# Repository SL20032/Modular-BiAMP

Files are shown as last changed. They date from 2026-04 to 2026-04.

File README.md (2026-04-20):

# Modular-BiAMP
Sample Modular Bi-AMP designed to work with Technics HD501 speakers (bc ampilifre in mine died). Project in active development.

## Modules
- Crosover PCB - Simple Active opamp based crosover providing 80db/dec attenuation. Components selected for 20 Hz to 3kHz passband for low freq part and 3kHz to 20kHz passband for high freq part.
- Power Amp PCB - Amplifire (AB-class) board using LM3886 for low frequence part (woofers) and LM4766 for high Frequency parts (tweeters)

## Fotos
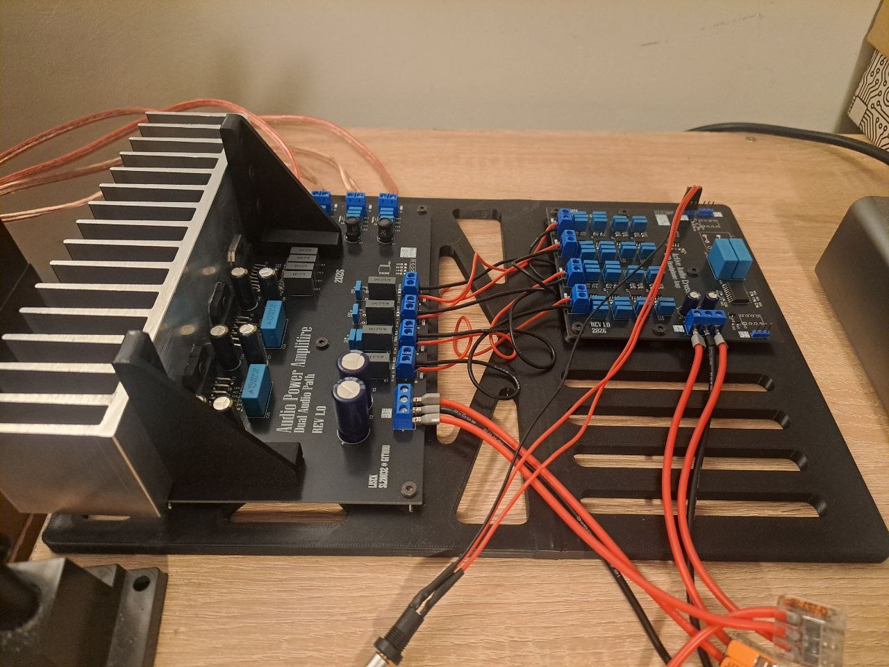
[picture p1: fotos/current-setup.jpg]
Current progress


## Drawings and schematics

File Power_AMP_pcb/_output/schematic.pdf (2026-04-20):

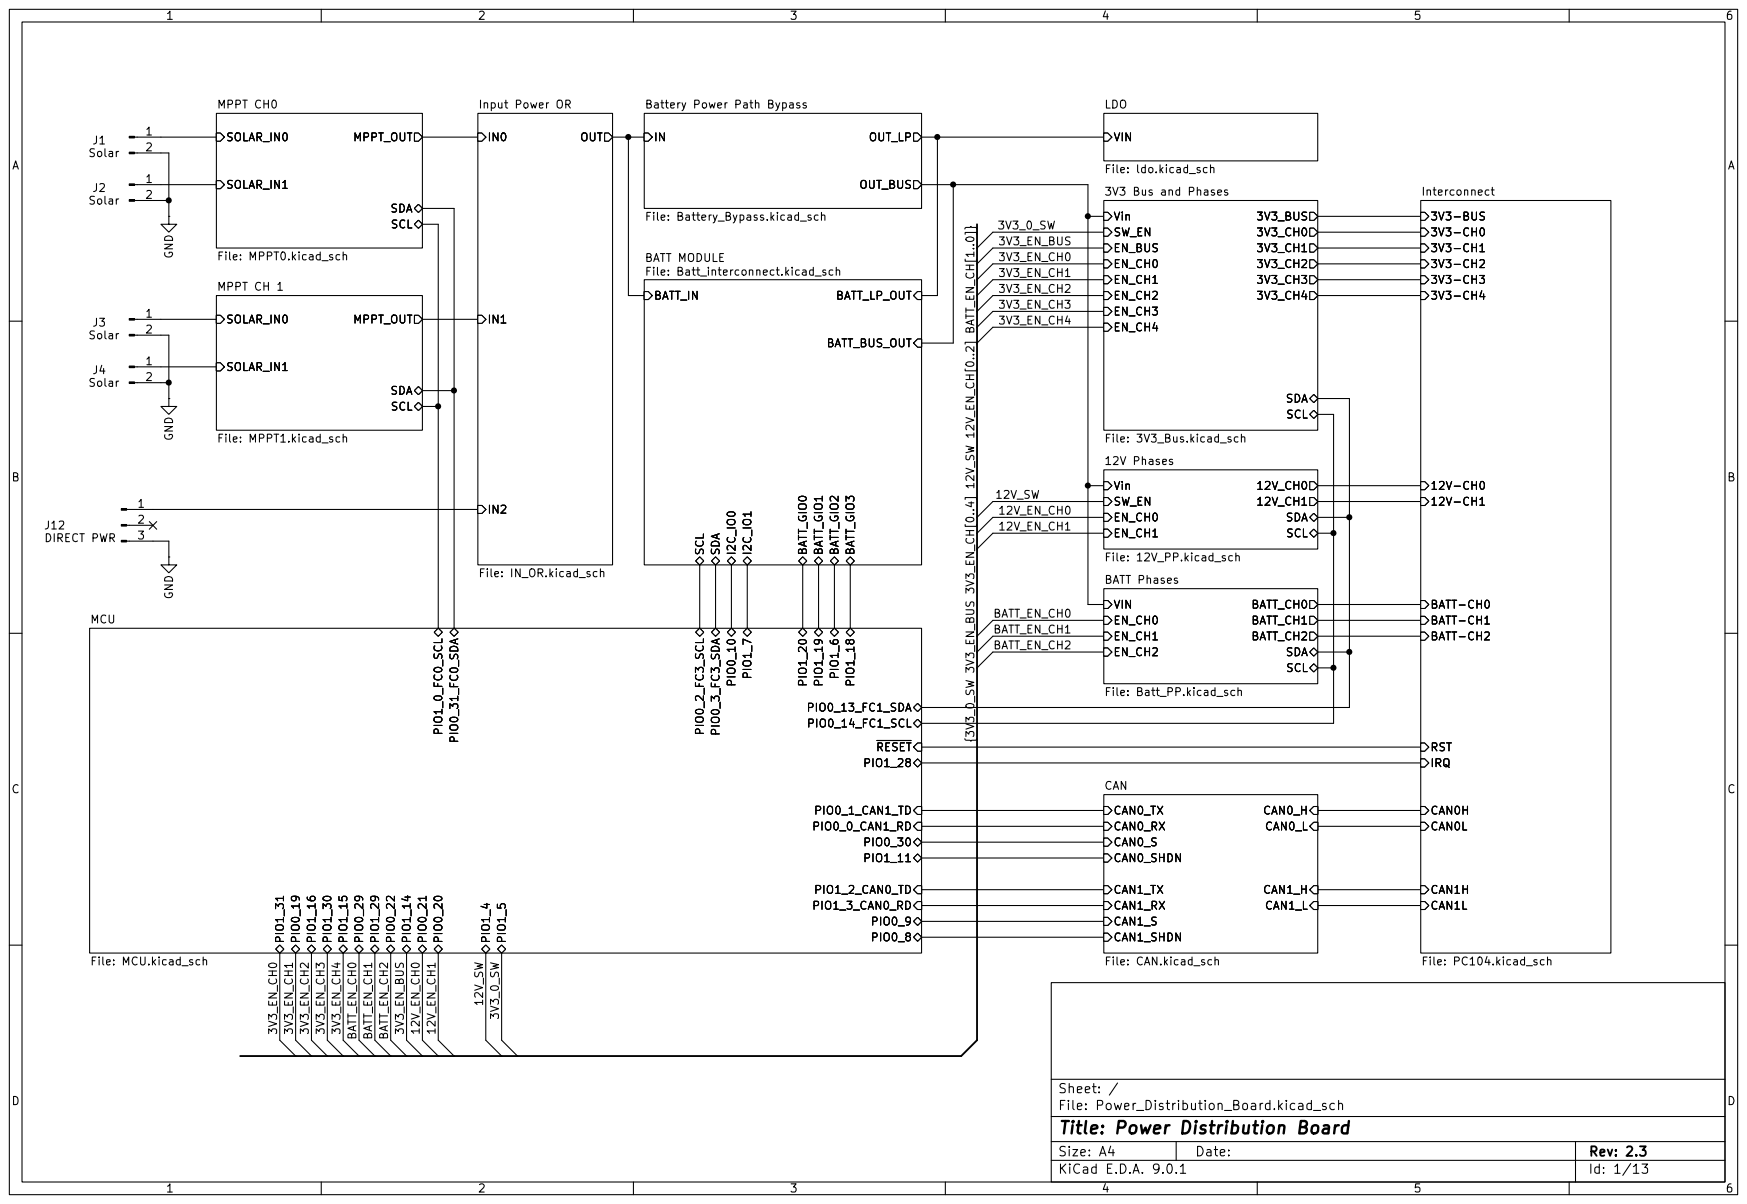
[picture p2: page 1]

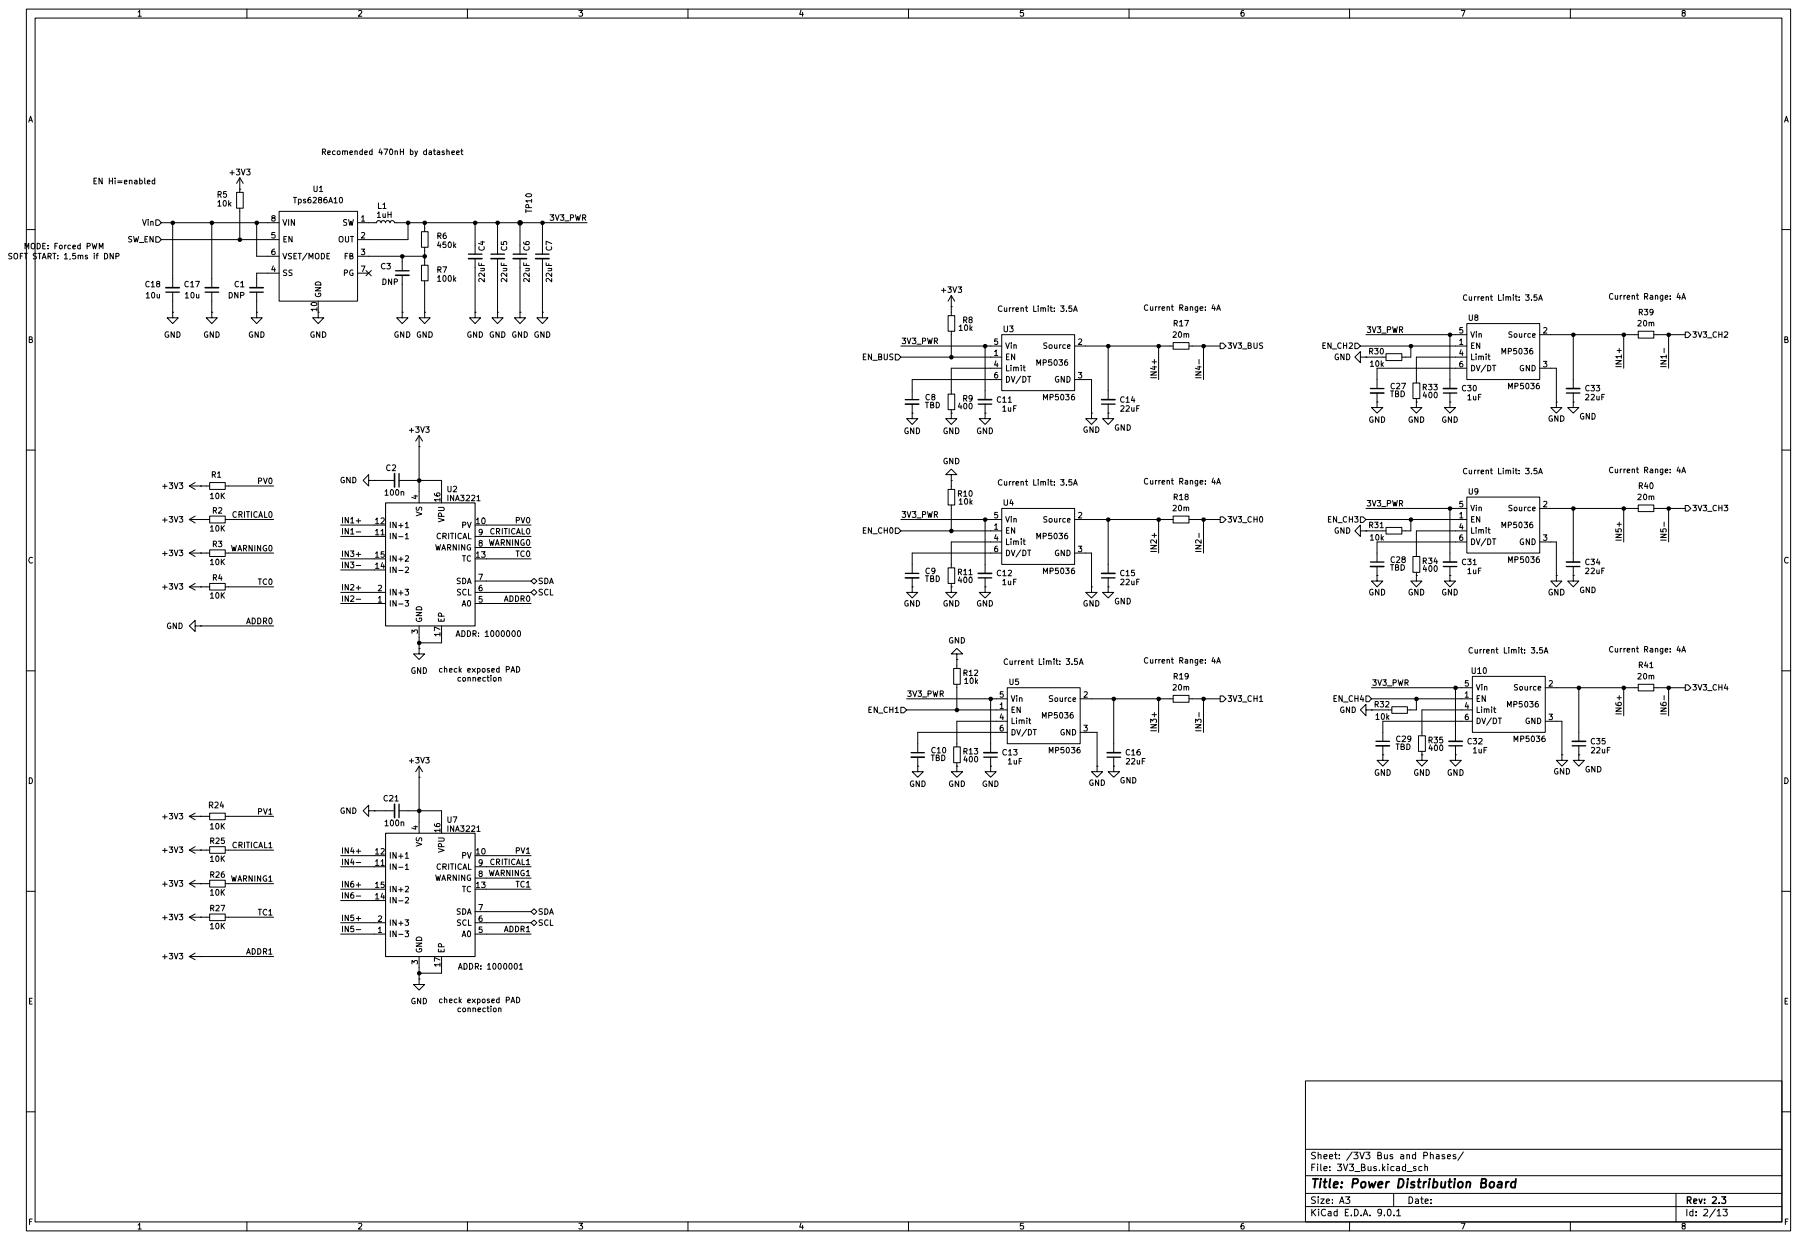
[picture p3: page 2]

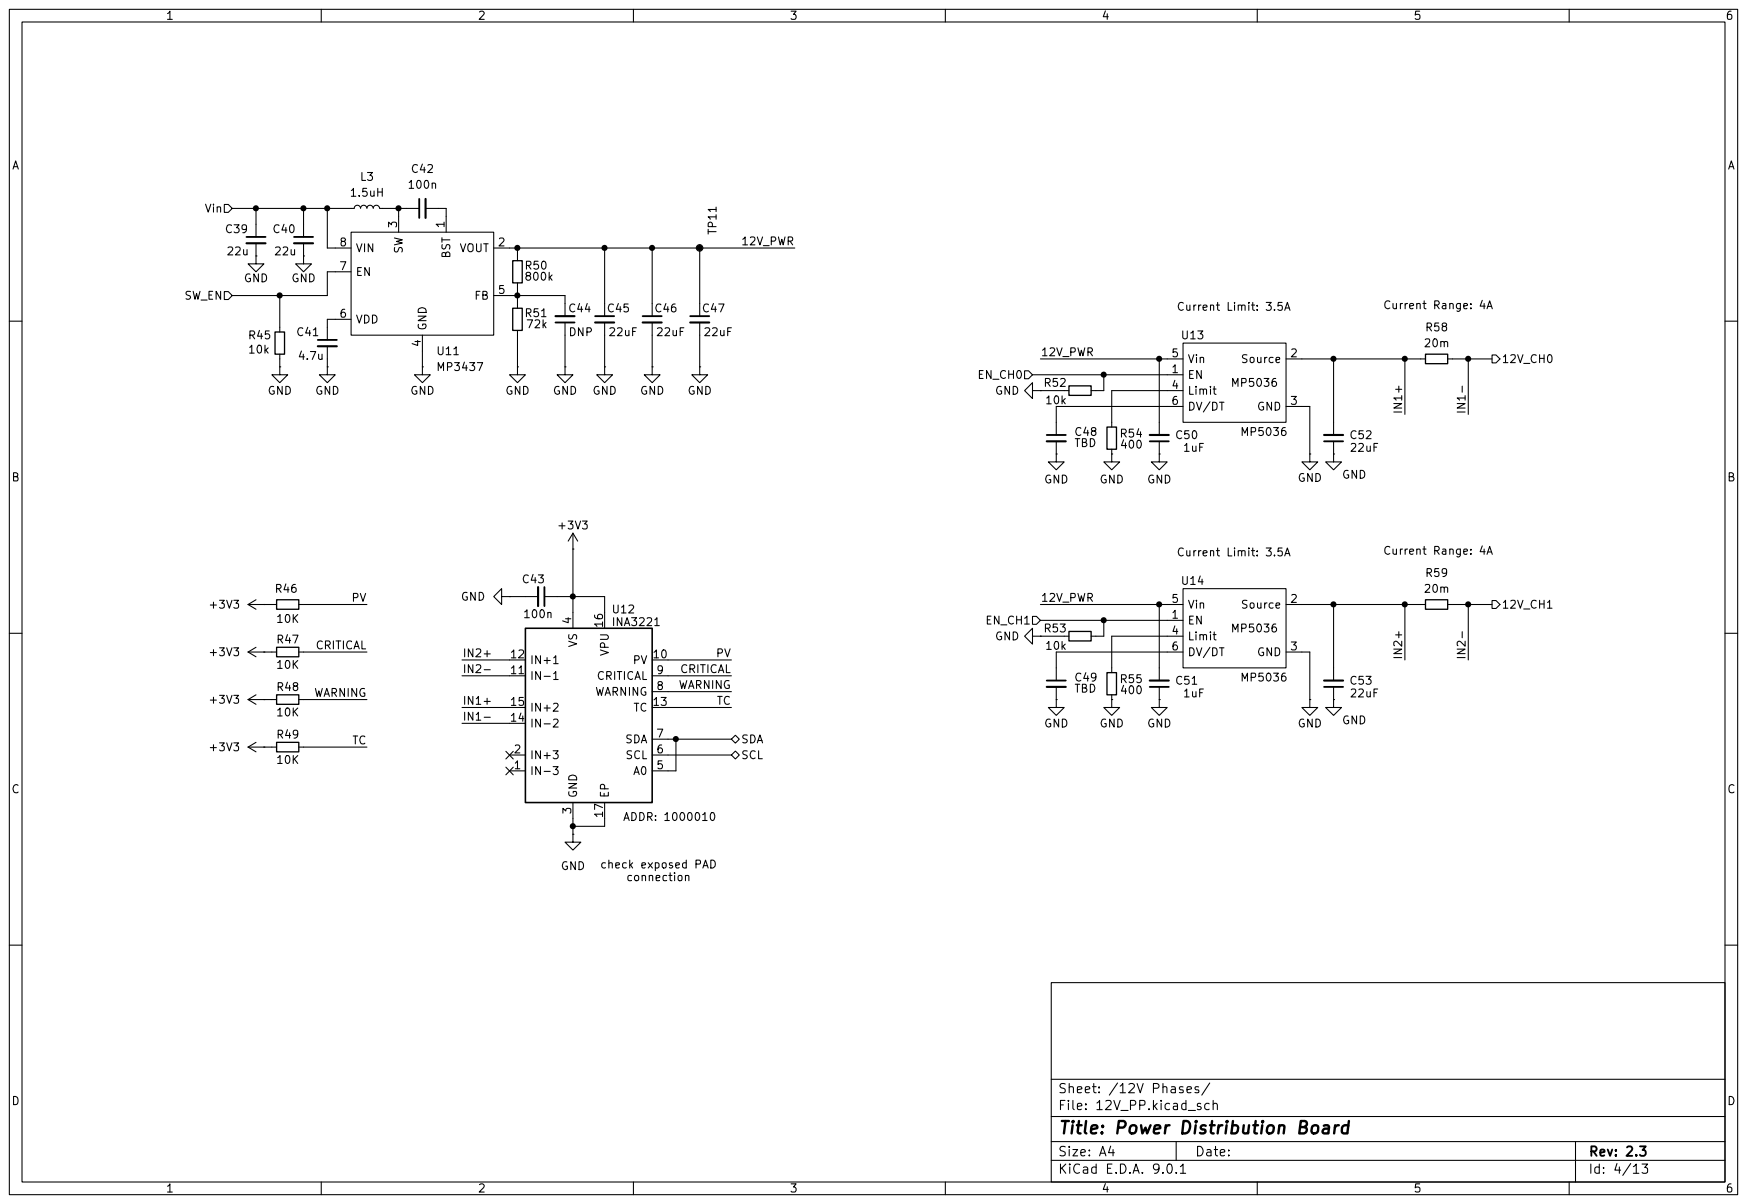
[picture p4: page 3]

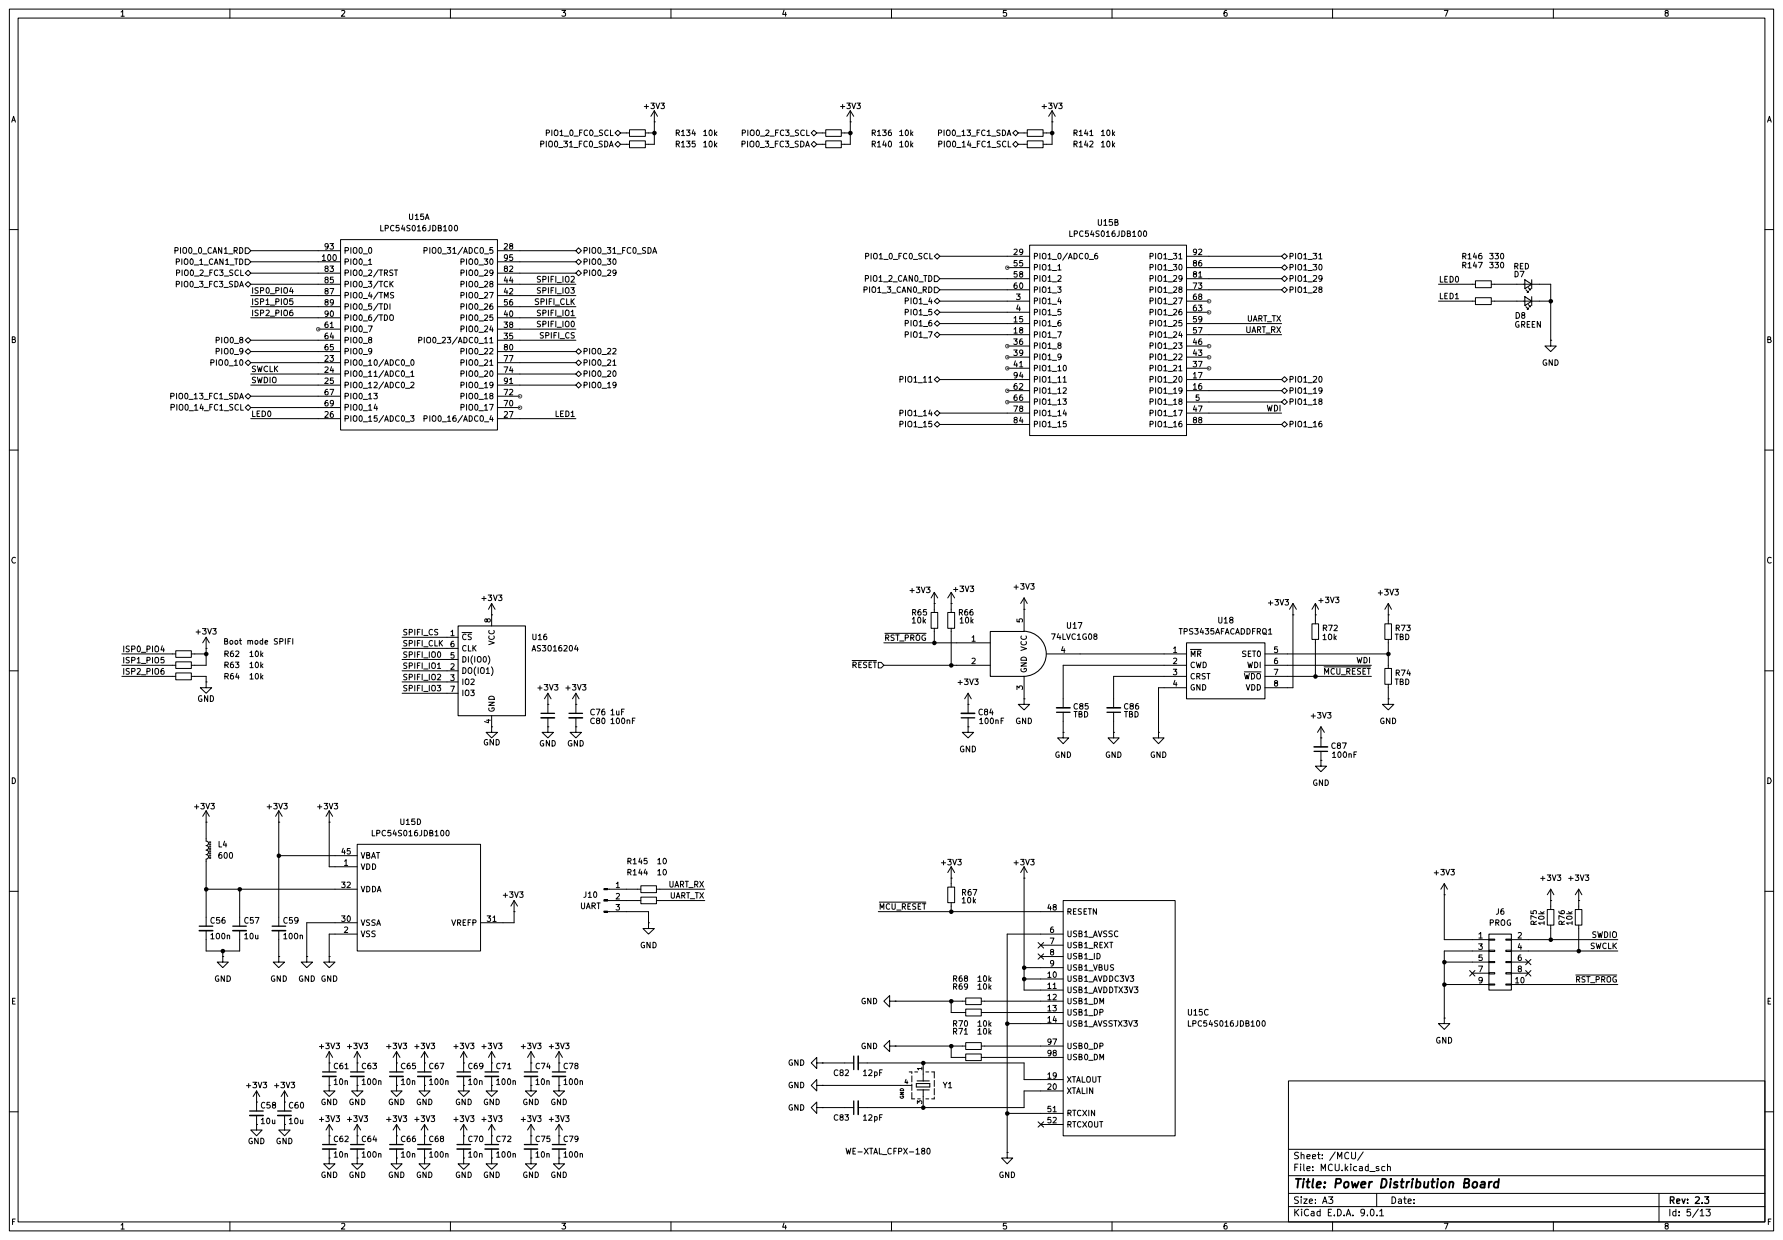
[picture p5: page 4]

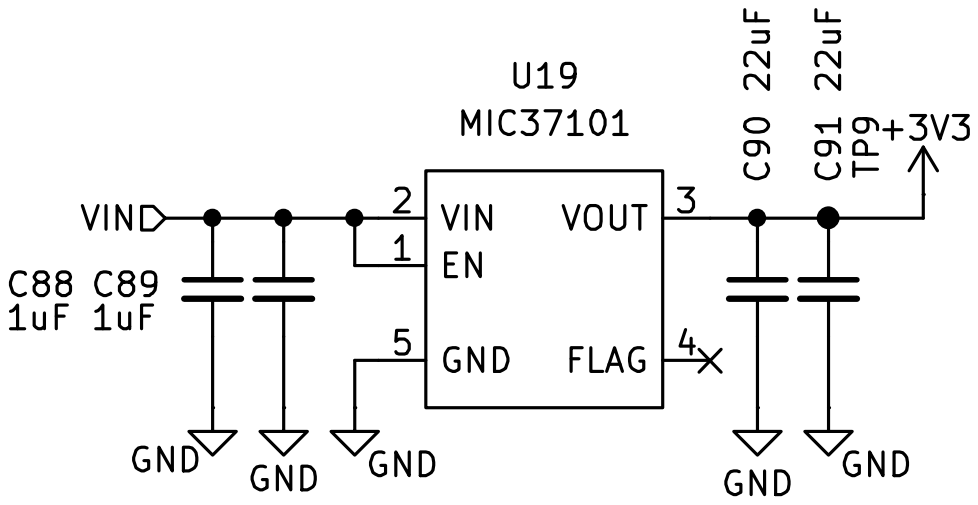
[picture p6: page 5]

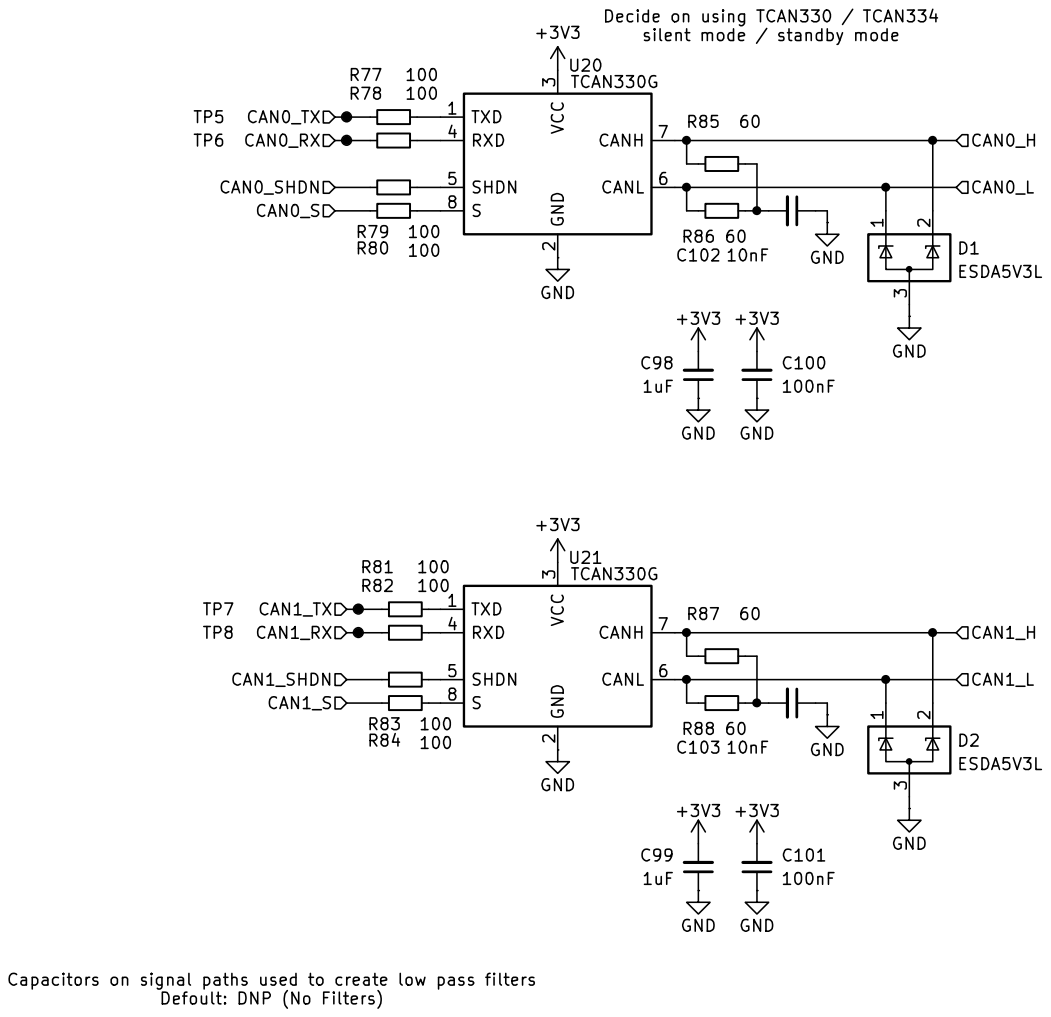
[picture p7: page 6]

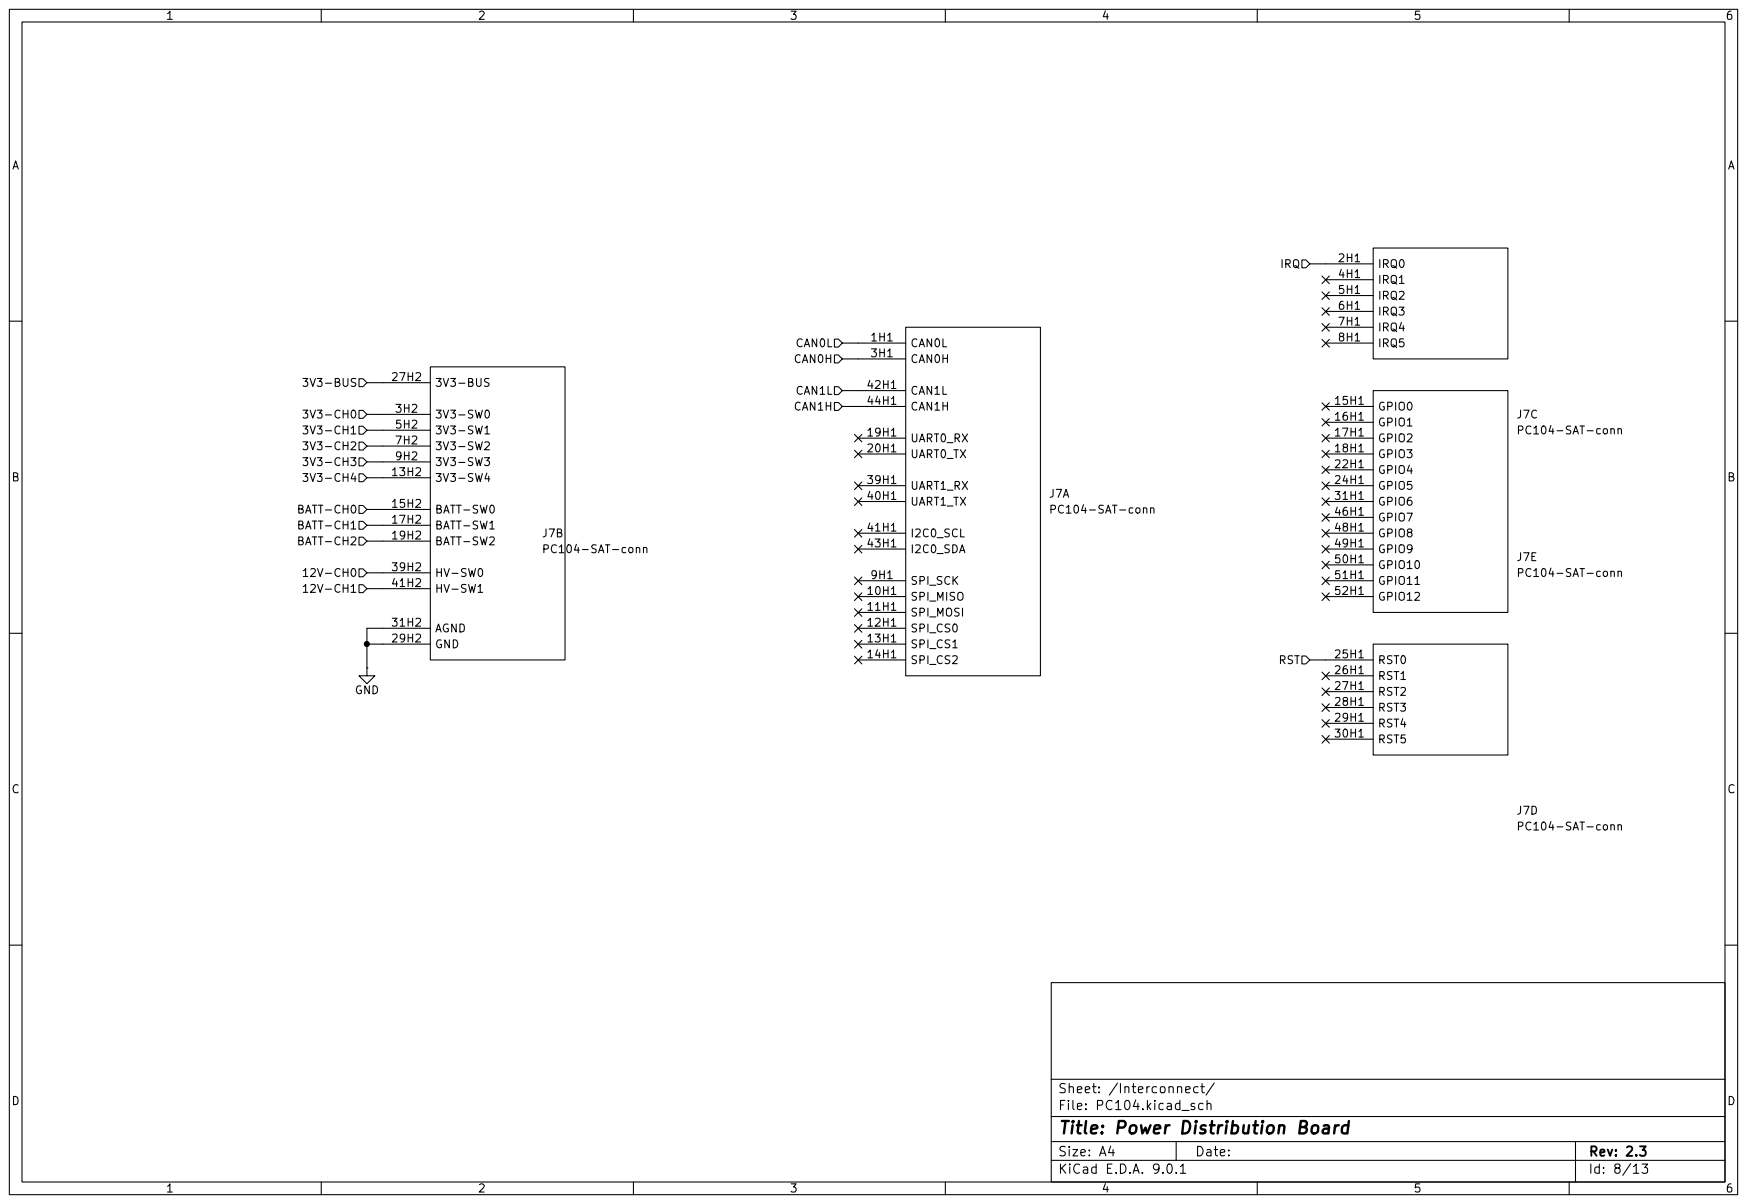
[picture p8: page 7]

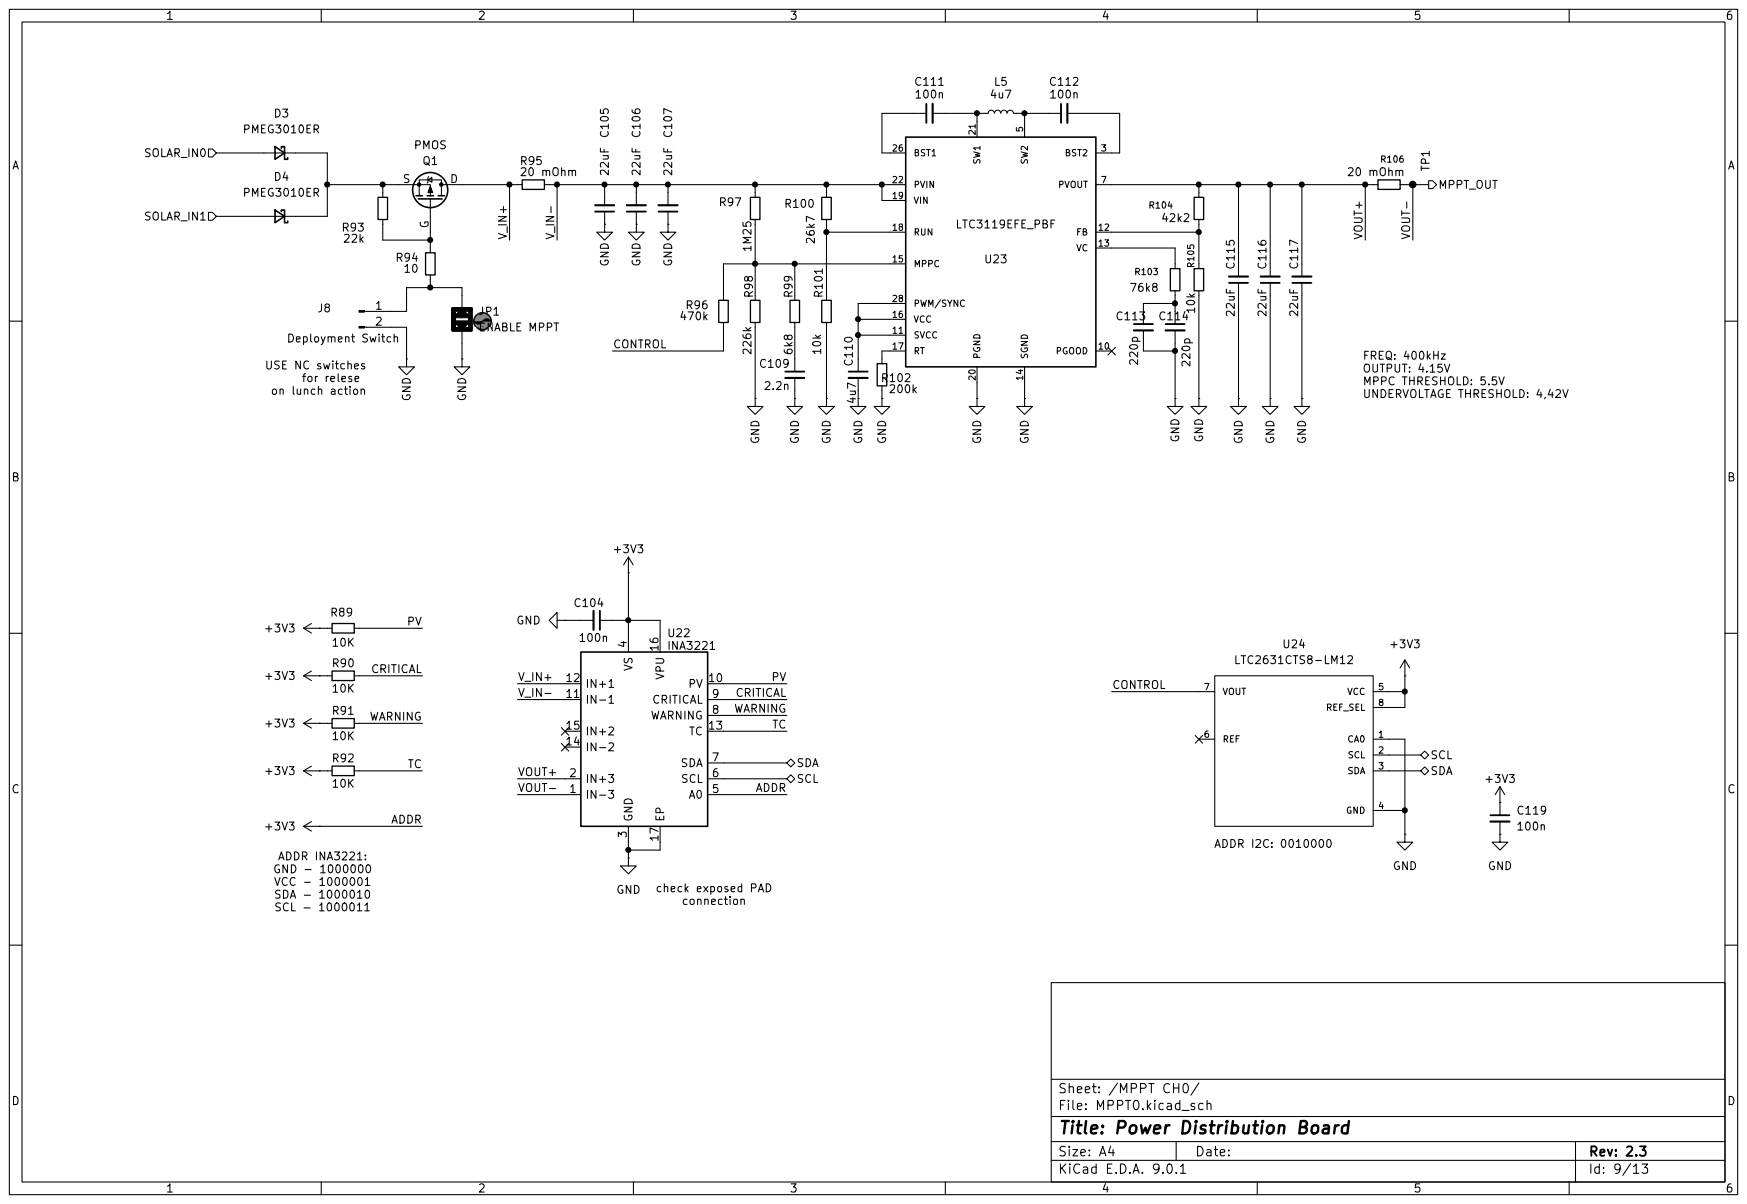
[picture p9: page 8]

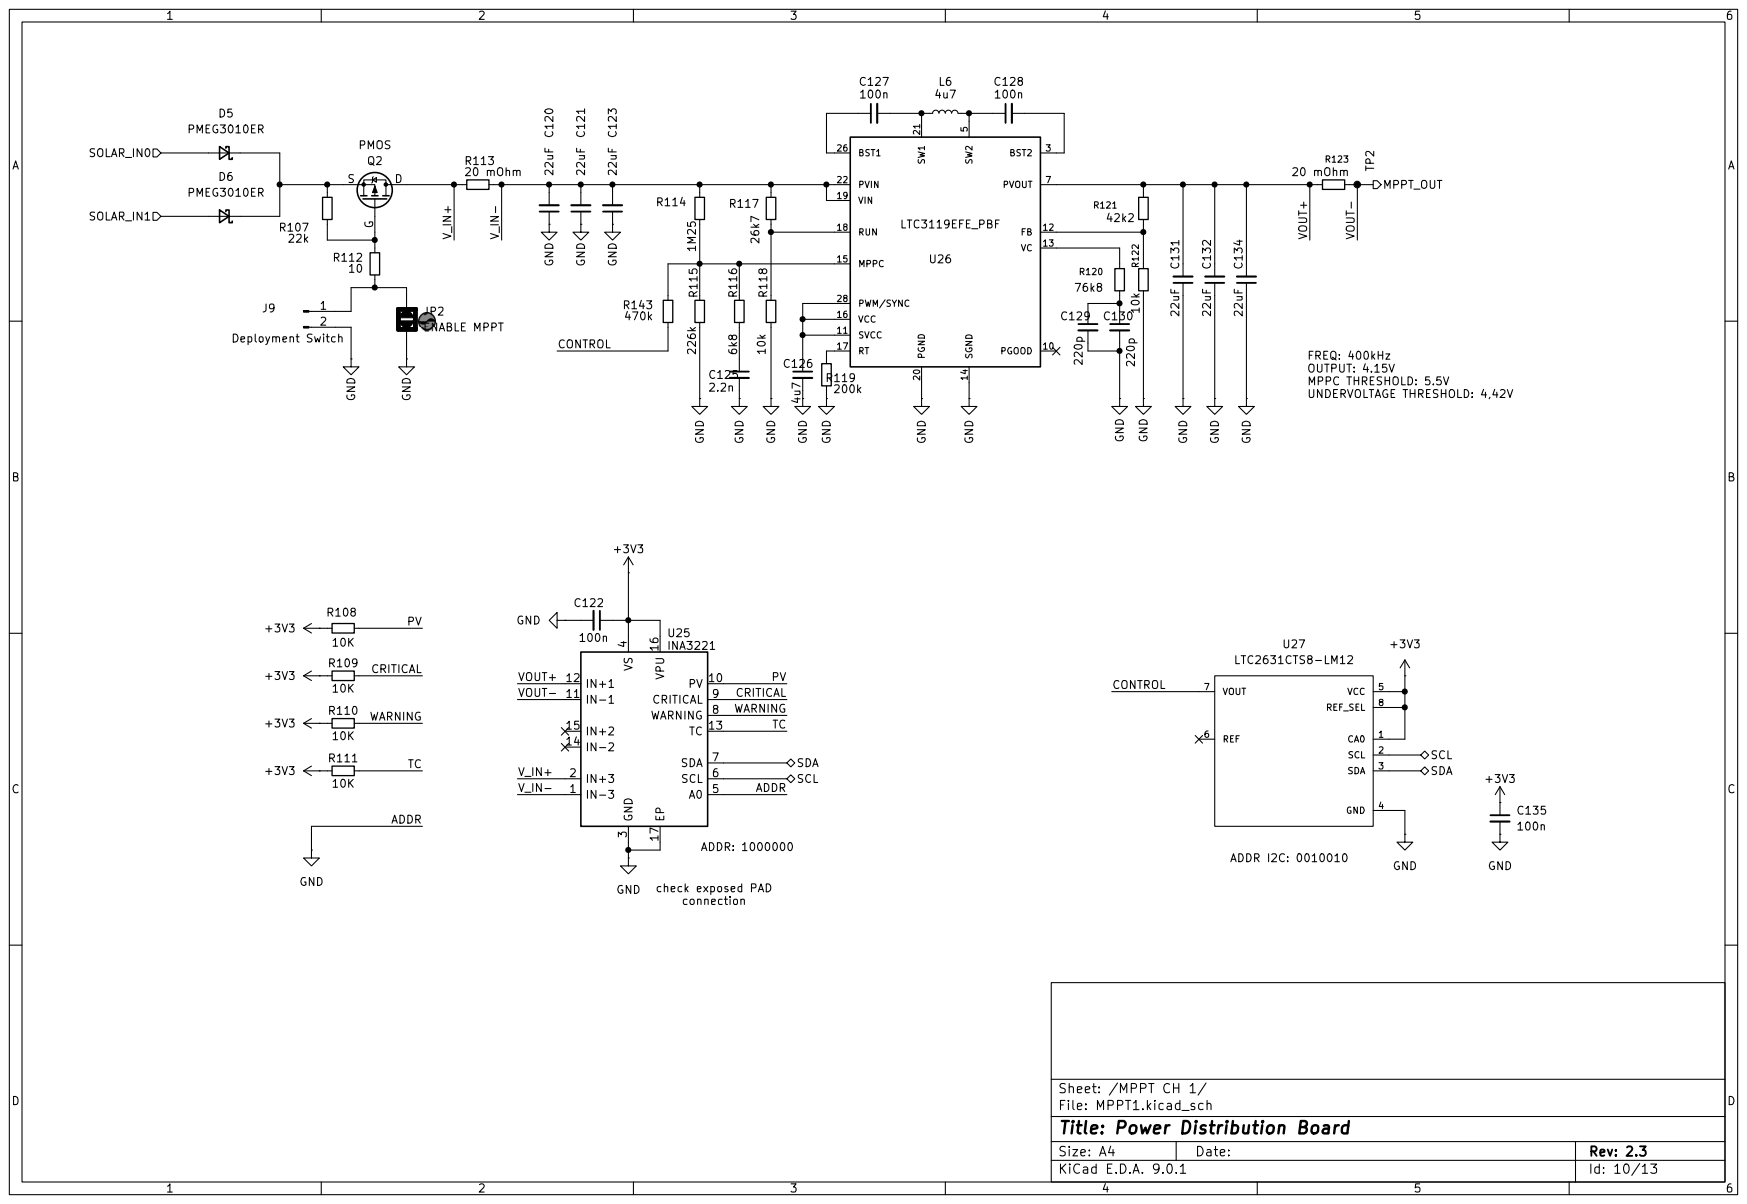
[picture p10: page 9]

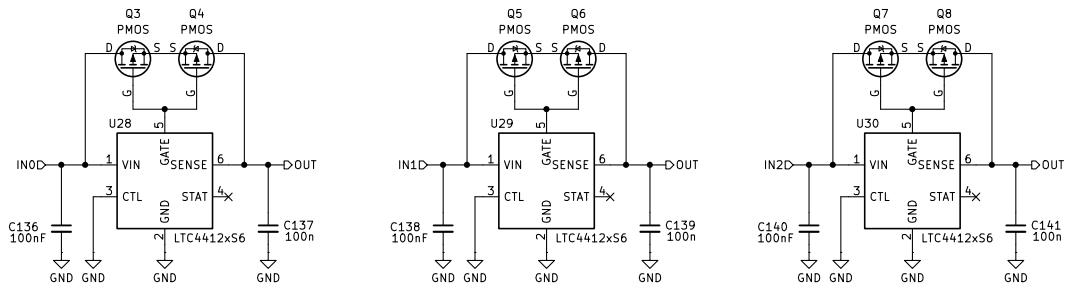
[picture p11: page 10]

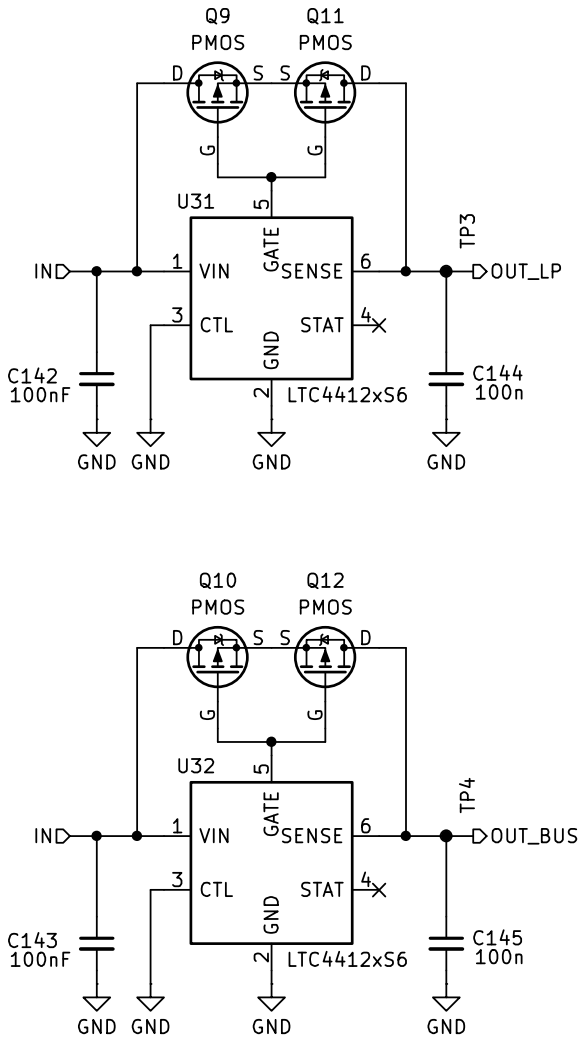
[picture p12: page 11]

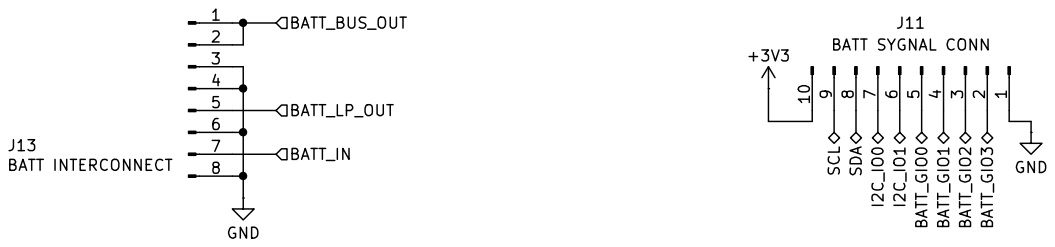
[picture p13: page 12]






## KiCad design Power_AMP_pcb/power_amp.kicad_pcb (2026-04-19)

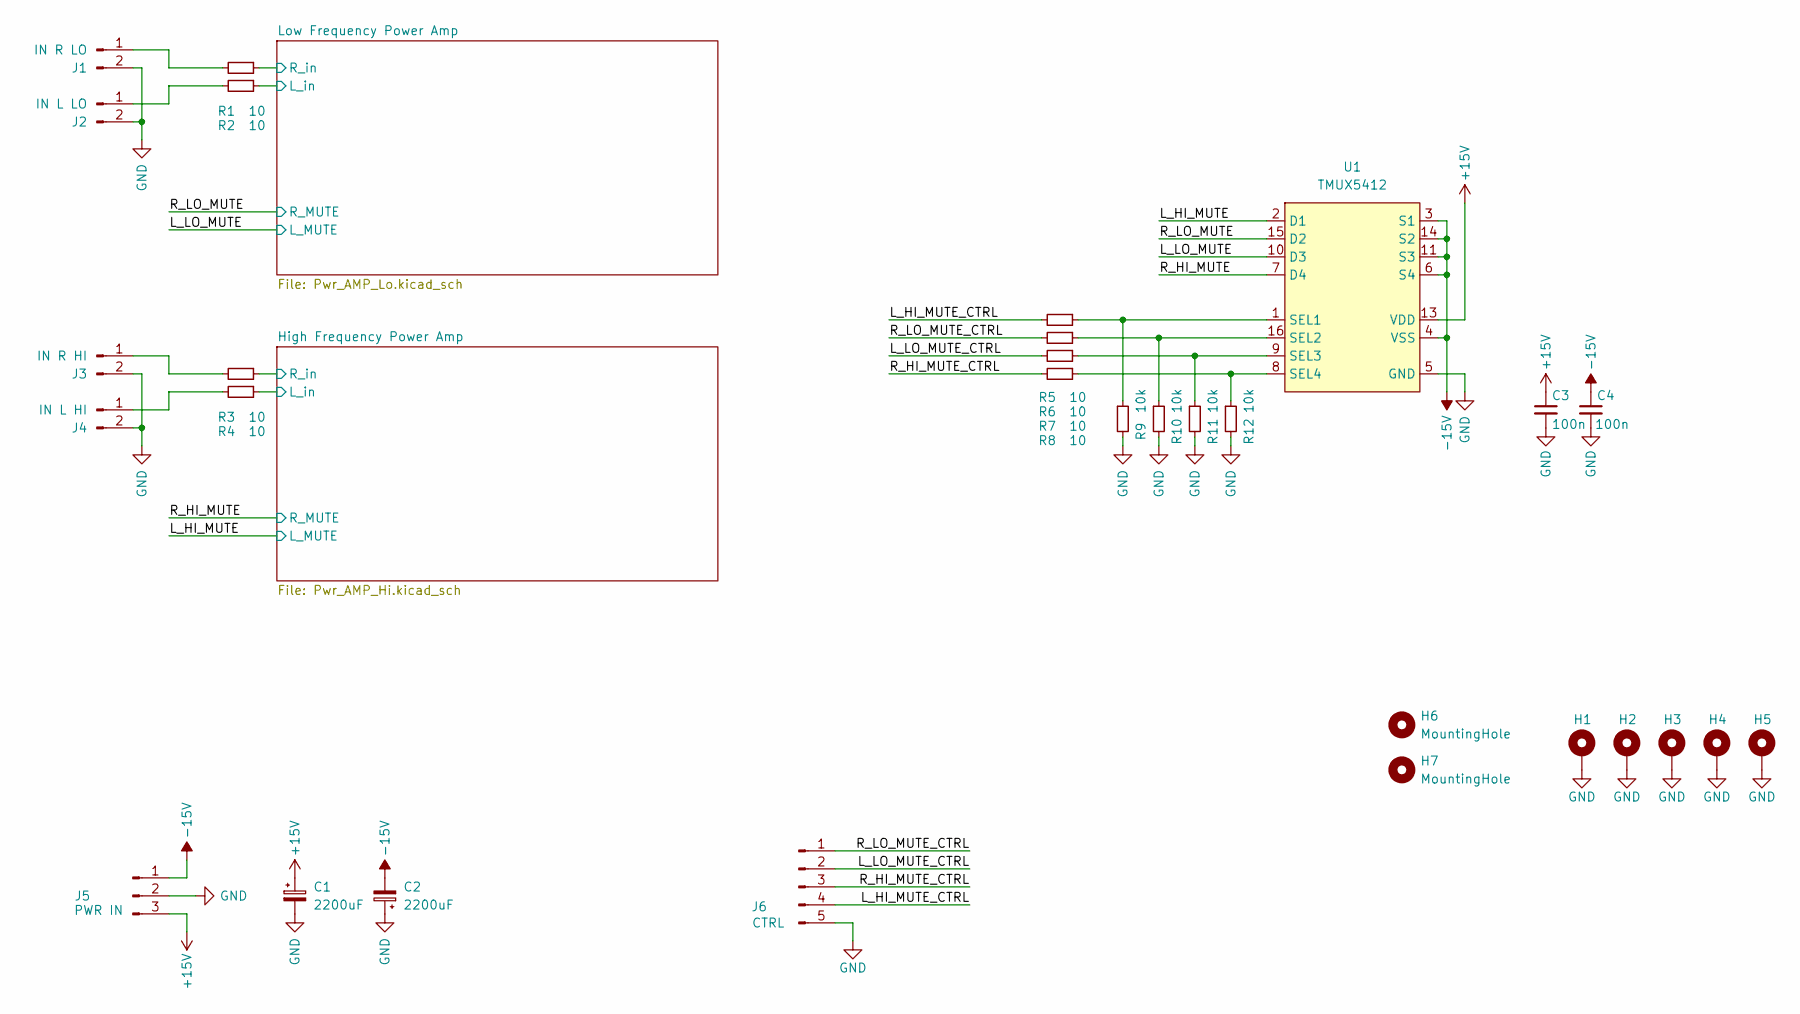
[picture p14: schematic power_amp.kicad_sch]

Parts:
C1, C2: 2200uF; CP_Radial_D12.5mm_P5.00mm
C3, C4: 100n; C_0805_2012Metric_Pad1.18x1.45mm_HandSolder
H1, H2, H3, H4, H5: MountingHole_Pad; MountingHole_3.2mm_M3_DIN965_Pad
H6, H7: MountingHole; Mounting_slots
J1: IN R LO; JST_NV_B02P-NV_1x02_P5.00mm_Vertical
J2: IN L LO; JST_NV_B02P-NV_1x02_P5.00mm_Vertical
J3: IN R HI; JST_NV_B02P-NV_1x02_P5.00mm_Vertical
J4: IN L HI; JST_NV_B02P-NV_1x02_P5.00mm_Vertical
J5: PWR IN; JST_NV_B03P-NV_1x03_P5.00mm_Vertical
J6: CTRL; PinHeader_1x05_P2.54mm_Vertical
R1, R2, R3, R4, R5, R6, R7, R8: 10; R_0805_2012Metric_Pad1.20x1.40mm_HandSolder
R9, R10, R11, R12: 10k; R_0805_2012Metric_Pad1.20x1.40mm_HandSolder
U1: TMUX5412; TSSOP-16_4.4x5mm_P0.65mm

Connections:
+15V: C1.1, C3.1, J5.3, U1.13 (VDD); also elsewhere on the board
-15V: C2.2, C4.1, J5.1, U1.3 (S1), U1.4 (VSS), U1.6 (S4), U1.11 (S3), U1.14 (S2); also elsewhere on the board
/High Frequency Power Amp/L_in: R4.1; also elsewhere on the board
/High Frequency Power Amp/R_in: R3.1; also elsewhere on the board
/L_HI_MUTE: U1.2 (D1); also elsewhere on the board
/L_HI_MUTE_CTRL: J6.4, R5.2
/L_LO_MUTE: U1.10 (D3); also elsewhere on the board
/L_LO_MUTE_CTRL: J6.2, R7.2
/Low Frequency Power Amp/L_in: R2.1; also elsewhere on the board
/Low Frequency Power Amp/R_in: R1.1; also elsewhere on the board
/R_HI_MUTE: U1.7 (D4); also elsewhere on the board
/R_HI_MUTE_CTRL: J6.3, R8.2
/R_LO_MUTE: U1.15 (D2); also elsewhere on the board
/R_LO_MUTE_CTRL: J6.1, R6.2
GND: C1.2, C2.1, C3.2, C4.2, H1.1, H2.1, H3.1, H4.1, H5.1, J1.2, J2.2, J3.2, J4.2, J5.2, J6.5, R9.2, R10.2, R11.2, R12.2, U1.5 (GND); also elsewhere on the board
unnamed: J1.1, R1.2
unnamed: J2.1, R2.2
unnamed: J3.1, R3.2
unnamed: J4.1, R4.2
unnamed: R5.1, R9.1, U1.1 (SEL1)
unnamed: R6.1, R10.1, U1.16 (SEL2)
unnamed: R7.1, R11.1, U1.9 (SEL3)
unnamed: R8.1, R12.1, U1.8 (SEL4)

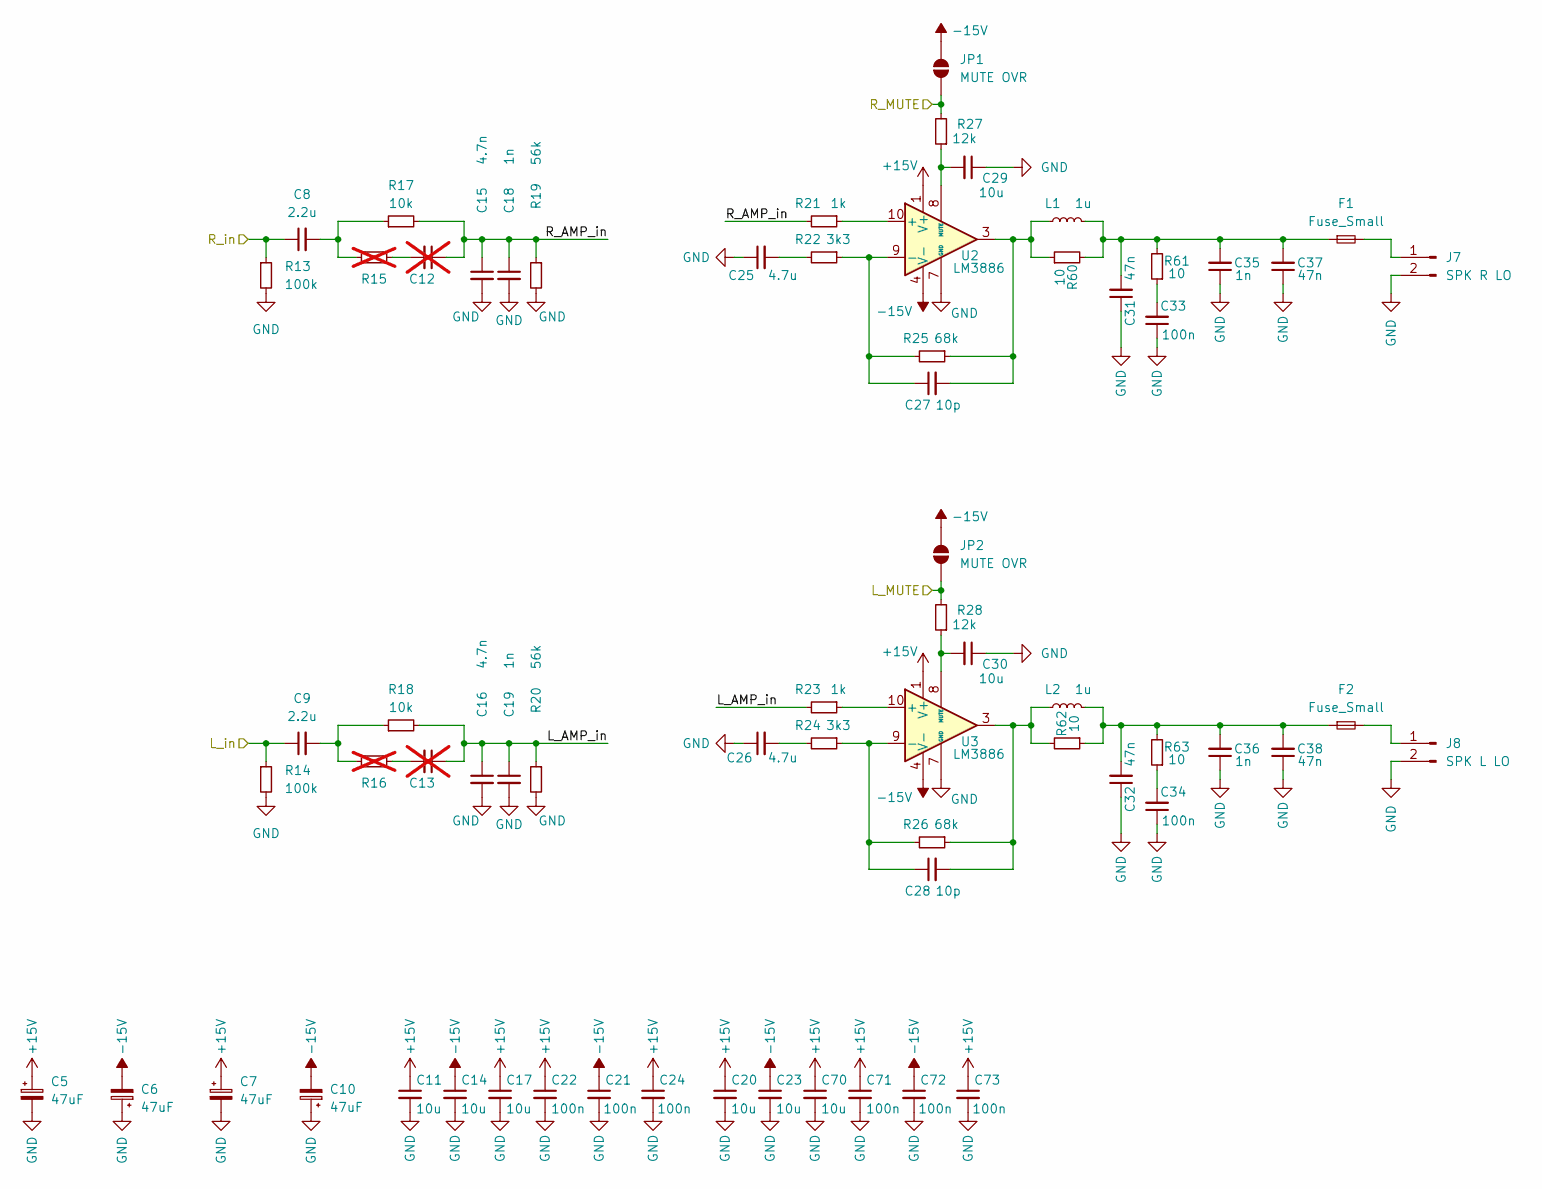
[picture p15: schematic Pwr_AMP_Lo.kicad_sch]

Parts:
C5, C6, C7, C10: 47uF; CP_Radial_D8.0mm_P3.50mm
C8, C9: 2.2u; C_Rect_L11.0mm_W5.1mm_P10.00mm_MKT
C11, C14, C17, C20, C23, C70: 10u; C_0805_2012Metric_Pad1.18x1.45mm_HandSolder
C12, C13: C_0805_2012Metric_Pad1.18x1.45mm_HandSolder; not fitted
C15, C16: 4.7n; C_Rect_L7.2mm_W2.5mm_P5.00mm_FKS2_FKP2_MKS2_MKP2
C18, C19, C35, C36: 1n; C_Rect_L7.2mm_W2.5mm_P5.00mm_FKS2_FKP2_MKS2_MKP2
C21, C22, C24, C71, C72, C73: 100n; C_0805_2012Metric_Pad1.18x1.45mm_HandSolder
C25, C26: 4.7u; C_Rect_L18.0mm_W7.0mm_P15.00mm_FKS3_FKP3
C27, C28: 10p; C_0805_2012Metric_Pad1.18x1.45mm_HandSolder
C29, C30: 10u; C_0805_2012Metric
C31, C32, C37, C38: 47n; C_Rect_L7.2mm_W2.5mm_P5.00mm_FKS2_FKP2_MKS2_MKP2
C33, C34: 100n; C_Rect_L7.2mm_W2.5mm_P5.00mm_FKS2_FKP2_MKS2_MKP2
F1, F2: Fuse_Small; Fuse_1206_3216Metric_Pad1.42x1.75mm_HandSolder
J7: SPK R LO; JST_NV_B02P-NV_1x02_P5.00mm_Vertical
J8: SPK L LO; JST_NV_B02P-NV_1x02_P5.00mm_Vertical
JP1, JP2: MUTE OVR; SolderJumper-2_P1.3mm_Open_RoundedPad1.0x1.5mm
L1, L2: 1u; L_Radial_D8.7mm_P5.00mm_Fastron_07HCP
R13, R14: 100k; R_0805_2012Metric_Pad1.20x1.40mm_HandSolder
R15, R16: R_0805_2012Metric_Pad1.20x1.40mm_HandSolder; not fitted
R17, R18: 10k; R_0805_2012Metric_Pad1.20x1.40mm_HandSolder
R19, R20: 56k; R_0805_2012Metric_Pad1.20x1.40mm_HandSolder
R21, R23: 1k; R_0805_2012Metric_Pad1.20x1.40mm_HandSolder
R22, R24: 3k3; R_0805_2012Metric_Pad1.20x1.40mm_HandSolder
R25, R26: 68k; R_0805_2012Metric_Pad1.20x1.40mm_HandSolder
R27, R28: 12k; R_0805_2012Metric_Pad1.20x1.40mm_HandSolder
R60, R61, R62, R63: 10; R_1206_3216Metric_Pad1.30x1.75mm_HandSolder
U2, U3: LM3886; TO-220F-11_P3.4x5.08mm_StaggerOdd_Lead5.08mm_Vertical

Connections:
+15V: C5.1, C7.1, C11.1, C17.1, C20.1, C22.1, C24.1, C70.1, C71.1, C73.1, U2.1 (V+), U2.5 (V+), U3.1 (V+), U3.5 (V+); also elsewhere on the board
-15V: C6.2, C10.2, C14.1, C21.1, C23.1, C72.1, JP1.2 (B), JP2.2 (B), U2.4 (V-), U3.4 (V-); also elsewhere on the board
/L_LO_MUTE: JP2.1 (A), R28.2; also elsewhere on the board
/Low Frequency Power Amp/L_AMP_in: C13.1, C16.1, C19.1, R18.2, R20.1, R23.2
/Low Frequency Power Amp/L_in: C9.1, R14.1; also elsewhere on the board
/Low Frequency Power Amp/R_AMP_in: C12.1, C15.1, C18.1, R17.2, R19.1, R21.2
/Low Frequency Power Amp/R_in: C8.1, R13.1; also elsewhere on the board
/R_LO_MUTE: JP1.1 (A), R27.2; also elsewhere on the board
GND: C5.2, C6.1, C7.2, C10.1, C11.2, C14.2, C15.2, C16.2, C17.2, C18.2, C19.2, C20.2, C21.2, C22.2, C23.2, C24.2, C25.1, C26.1, C29.1, C30.1, C31.1, C32.1, C33.1, C34.1, C35.1, C36.1, C37.1, C38.1, C70.2, C71.2, C72.2, C73.2, J7.2, J8.2, R13.2, R14.2, R19.2, R20.2, U2.7 (GND), U3.7 (GND); also elsewhere on the board
unnamed: C8.2, R15.2, R17.1
unnamed: C9.2, R16.2, R18.1
unnamed: C12.2, R15.1
unnamed: C13.2, R16.1
unnamed: C25.2, R22.2
unnamed: C26.2, R24.2
unnamed: C27.2, L1.1, R25.1, R60.1, U2.3
unnamed: C28.2, L2.1, R26.1, R62.2, U3.3
unnamed: C31.2, C35.2, C37.2, F1.1, L1.2, R60.2, R61.2
unnamed: C32.2, C36.2, C38.2, F2.1, L2.2, R62.1, R63.2
unnamed: C33.2, R61.1
unnamed: C34.2, R63.1
unnamed: F1.2, J7.1
unnamed: F2.2, J8.1
unnamed: R21.1, U2.10 (+)
unnamed: C27.1, R22.1, R25.2, U2.9 (-)
unnamed: C29.2, R27.1, U2.8 (MUTE)
unnamed: R23.1, U3.10 (+)
unnamed: C28.1, R24.1, R26.2, U3.9 (-)
unnamed: C30.2, R28.1, U3.8 (MUTE)

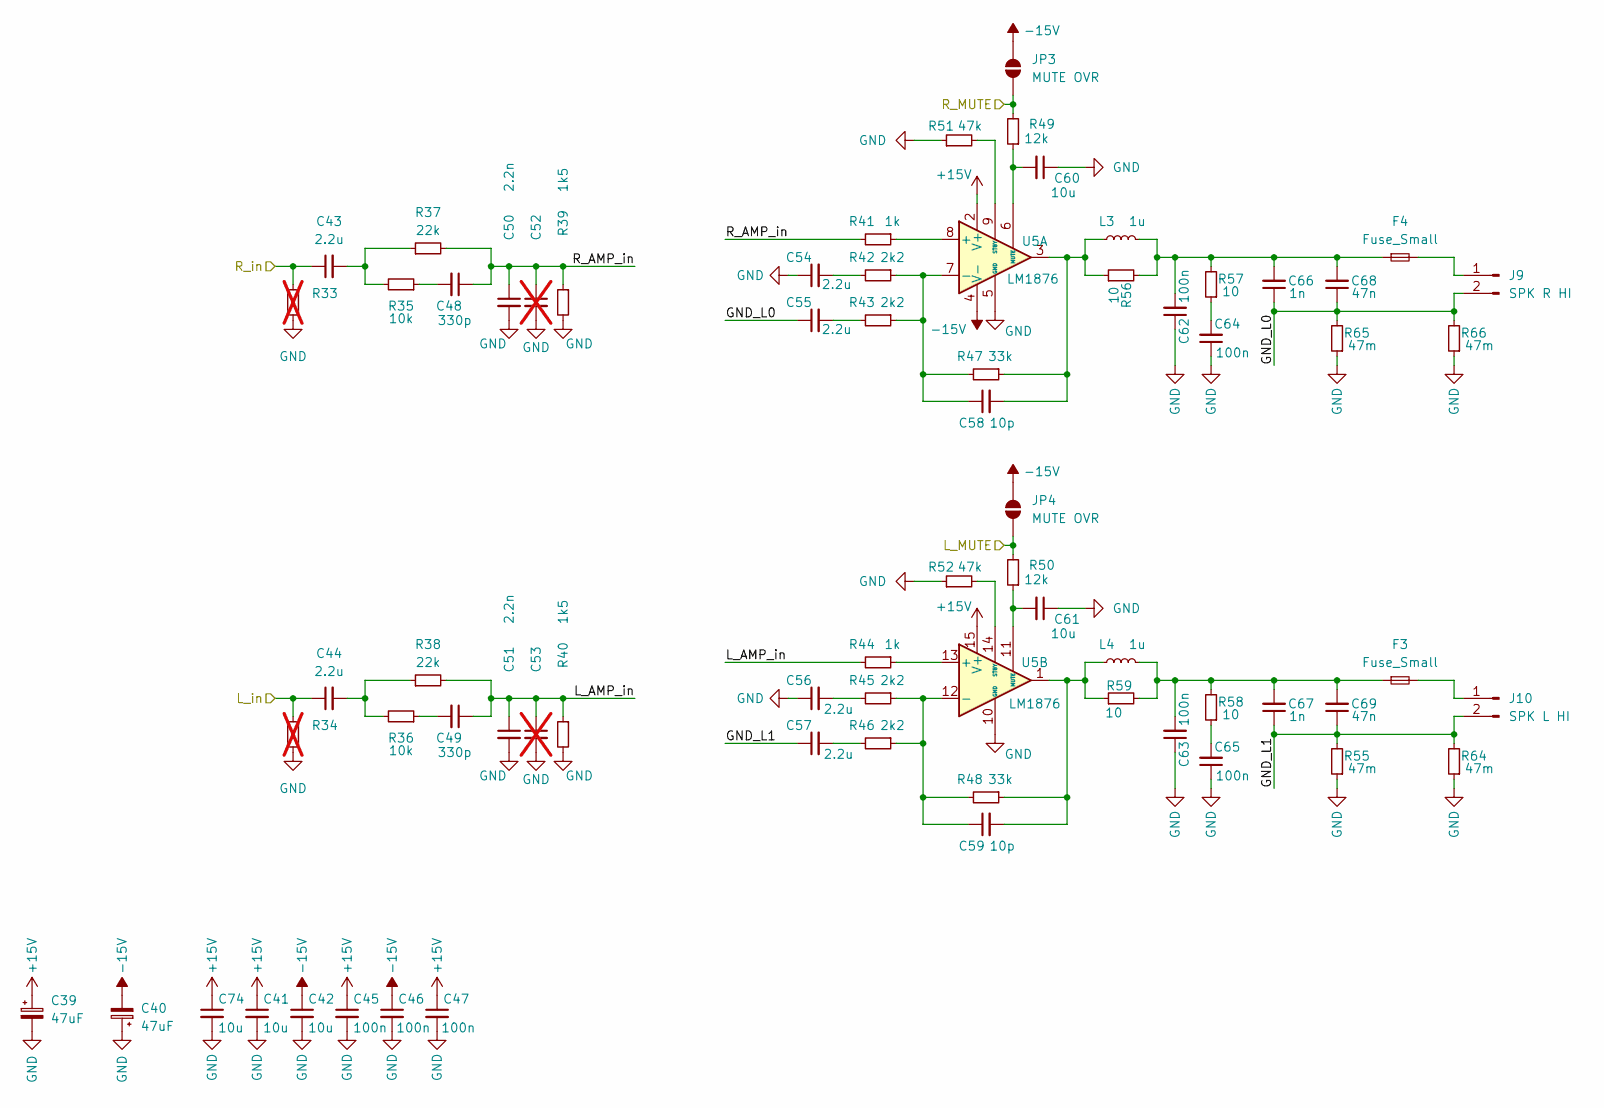
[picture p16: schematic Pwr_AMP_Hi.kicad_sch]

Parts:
C39, C40: 47uF; CP_Radial_D8.0mm_P3.50mm
C41, C42, C60, C61, C74: 10u; C_0805_2012Metric_Pad1.18x1.45mm_HandSolder
C43, C44, C54, C55, C56, C57: 2.2u; C_Rect_L11.0mm_W5.1mm_P10.00mm_MKT
C45, C46, C47: 100n; C_0805_2012Metric_Pad1.18x1.45mm_HandSolder
C48, C49: 330p; C_0805_2012Metric_Pad1.18x1.45mm_HandSolder
C50, C51: 2.2n; C_Rect_L7.2mm_W2.5mm_P5.00mm_FKS2_FKP2_MKS2_MKP2
C52, C53: C_Rect_L7.2mm_W2.5mm_P5.00mm_FKS2_FKP2_MKS2_MKP2; not fitted
C58, C59: 10p; C_0805_2012Metric_Pad1.18x1.45mm_HandSolder
C62, C63, C64, C65: 100n; C_Rect_L7.2mm_W2.5mm_P5.00mm_FKS2_FKP2_MKS2_MKP2
C66, C67: 1n; C_Rect_L7.2mm_W2.5mm_P5.00mm_FKS2_FKP2_MKS2_MKP2
C68, C69: 47n; C_Rect_L7.2mm_W2.5mm_P5.00mm_FKS2_FKP2_MKS2_MKP2
F3, F4: Fuse_Small; Fuse_1206_3216Metric_Pad1.42x1.75mm_HandSolder
J9: SPK R HI; JST_NV_B02P-NV_1x02_P5.00mm_Vertical
J10: SPK L HI; JST_NV_B02P-NV_1x02_P5.00mm_Vertical
JP3, JP4: MUTE OVR; SolderJumper-2_P1.3mm_Open_RoundedPad1.0x1.5mm
L3, L4: 1u; L_Radial_D8.7mm_P5.00mm_Fastron_07HCP
R33, R34: R_0805_2012Metric_Pad1.20x1.40mm_HandSolder; not fitted
R35, R36: 10k; R_0805_2012Metric_Pad1.20x1.40mm_HandSolder
R37, R38: 22k; R_0805_2012Metric_Pad1.20x1.40mm_HandSolder
R39, R40: 1k5; R_0805_2012Metric_Pad1.20x1.40mm_HandSolder
R41, R44: 1k; R_0805_2012Metric_Pad1.20x1.40mm_HandSolder
R42, R43, R45, R46: 2k2; R_0805_2012Metric_Pad1.20x1.40mm_HandSolder
R47, R48: 33k; R_0805_2012Metric_Pad1.20x1.40mm_HandSolder
R49, R50: 12k; R_0805_2012Metric_Pad1.20x1.40mm_HandSolder
R51, R52: 47k; R_0805_2012Metric_Pad1.20x1.40mm_HandSolder
R55, R64, R65, R66: 47m; R_1020_2550Metric_Pad1.33x5.20mm_HandSolder
R56, R57, R58, R59: 10; R_1206_3216Metric_Pad1.30x1.75mm_HandSolder
U5: LM1876; TO-220F-15_P2.54x5.08mm_StaggerOdd_Lead5.08mm_Vertical

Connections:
+15V: C39.1, C41.1, C45.1, C47.1, C74.1, U5.2 (V+), U5.15 (V+); also elsewhere on the board
-15V: C40.2, C42.1, C46.1, JP3.2 (B), JP4.2 (B), U5.4 (V-); also elsewhere on the board
/High Frequency Power Amp/GND_L0: C55.1, C66.1, C68.1, J9.2, R65.2, R66.2
/High Frequency Power Amp/GND_L1: C57.1, C67.1, C69.1, J10.2, R55.2, R64.2
/High Frequency Power Amp/L_AMP_in: C49.1, C51.1, C53.1, R38.2, R40.1, R44.2
/High Frequency Power Amp/L_in: C44.1, R34.1; also elsewhere on the board
/High Frequency Power Amp/R_AMP_in: C48.1, C50.1, C52.1, R37.2, R39.1, R41.2
/High Frequency Power Amp/R_in: C43.1, R33.1; also elsewhere on the board
/L_HI_MUTE: JP4.1 (A), R50.2; also elsewhere on the board
/R_HI_MUTE: JP3.1 (A), R49.2; also elsewhere on the board
GND: C39.2, C40.1, C41.2, C42.2, C45.2, C46.2, C47.2, C50.2, C51.2, C52.2, C53.2, C54.1, C56.1, C60.1, C61.1, C62.1, C63.1, C64.1, C65.1, C74.2, R33.2, R34.2, R39.2, R40.2, R51.1, R52.1, R55.1, R64.1, R65.1, R66.1, U5.5 (GND), U5.10 (GND); also elsewhere on the board
unnamed: C43.2, R35.2, R37.1
unnamed: C44.2, R36.2, R38.1
unnamed: C48.2, R35.1
unnamed: C49.2, R36.1
unnamed: C54.2, R42.2
unnamed: C55.2, R43.2
unnamed: C56.2, R45.2
unnamed: C57.2, R46.2
unnamed: C58.2, L3.1, R47.1, R56.1, U5.3
unnamed: C59.2, L4.1, R48.1, R59.1, U5.1
unnamed: C62.2, C66.2, C68.2, F4.1, L3.2, R56.2, R57.2
unnamed: C63.2, C67.2, C69.2, F3.1, L4.2, R58.2, R59.2
unnamed: C64.2, R57.1
unnamed: C65.2, R58.1
unnamed: F4.2, J9.1
unnamed: F3.2, J10.1
unnamed: R41.1, U5.8 (+)
unnamed: C58.1, R42.1, R43.1, R47.2, U5.7 (-)
unnamed: C60.2, R49.1, U5.6 (MUTE)
unnamed: R51.2, U5.9 (STBY)
unnamed: R44.1, U5.13 (+)
unnamed: C59.1, R45.1, R46.1, R48.2, U5.12 (-)
unnamed: C61.2, R50.1, U5.11 (MUTE)
unnamed: R52.2, U5.14 (STBY)

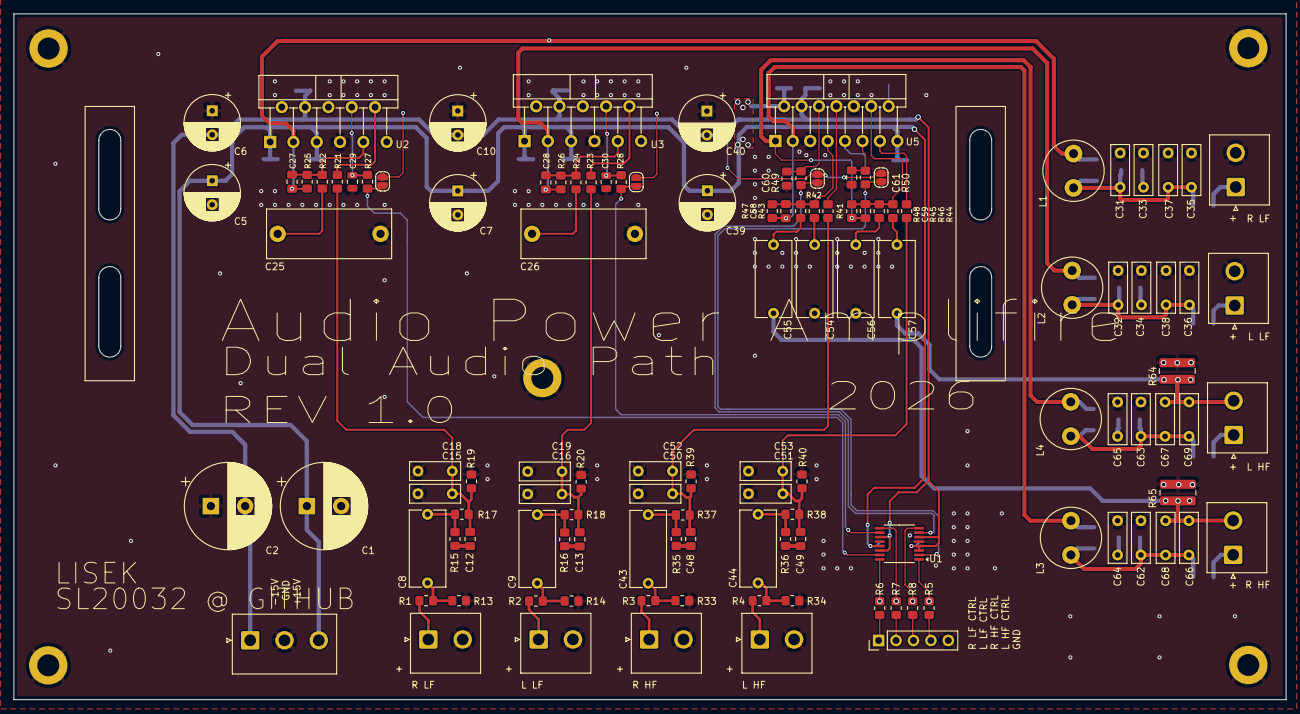
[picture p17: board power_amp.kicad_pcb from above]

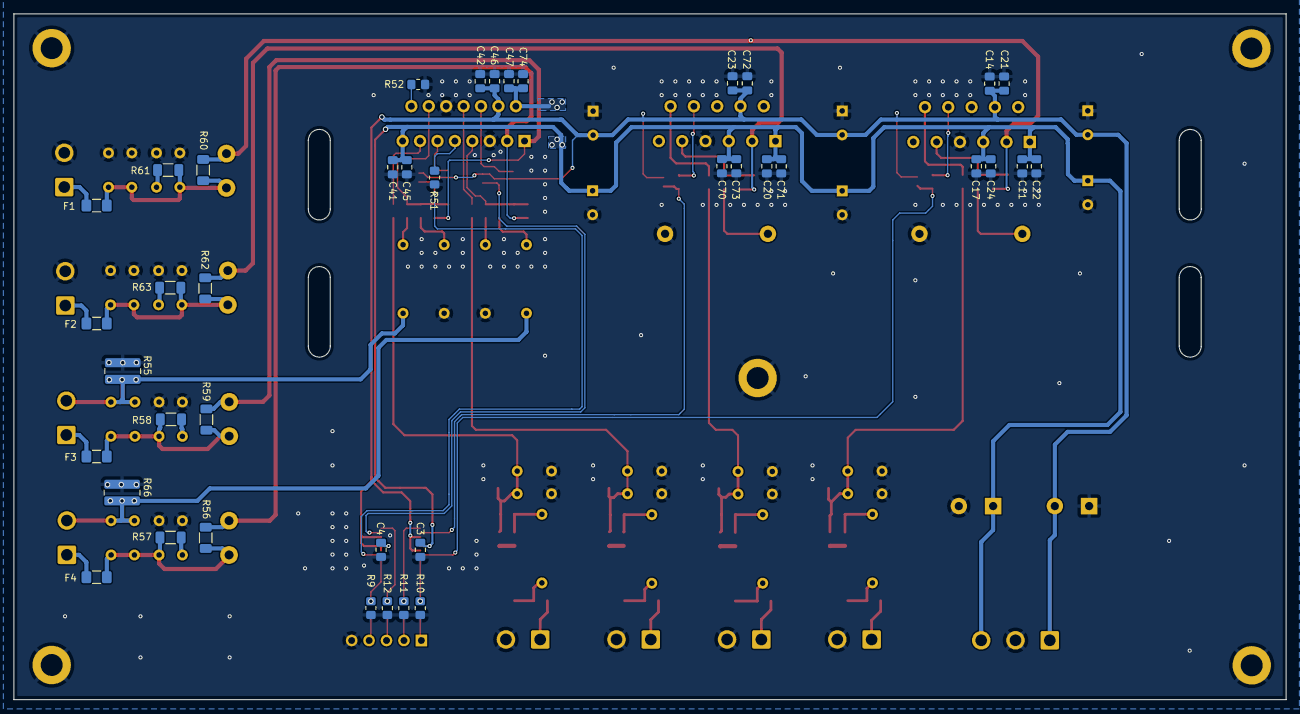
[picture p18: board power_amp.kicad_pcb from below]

Board: 2 copper layers, 185.5 x 100.0 mm, 167 parts (40 on the bottom side), 73 nets.

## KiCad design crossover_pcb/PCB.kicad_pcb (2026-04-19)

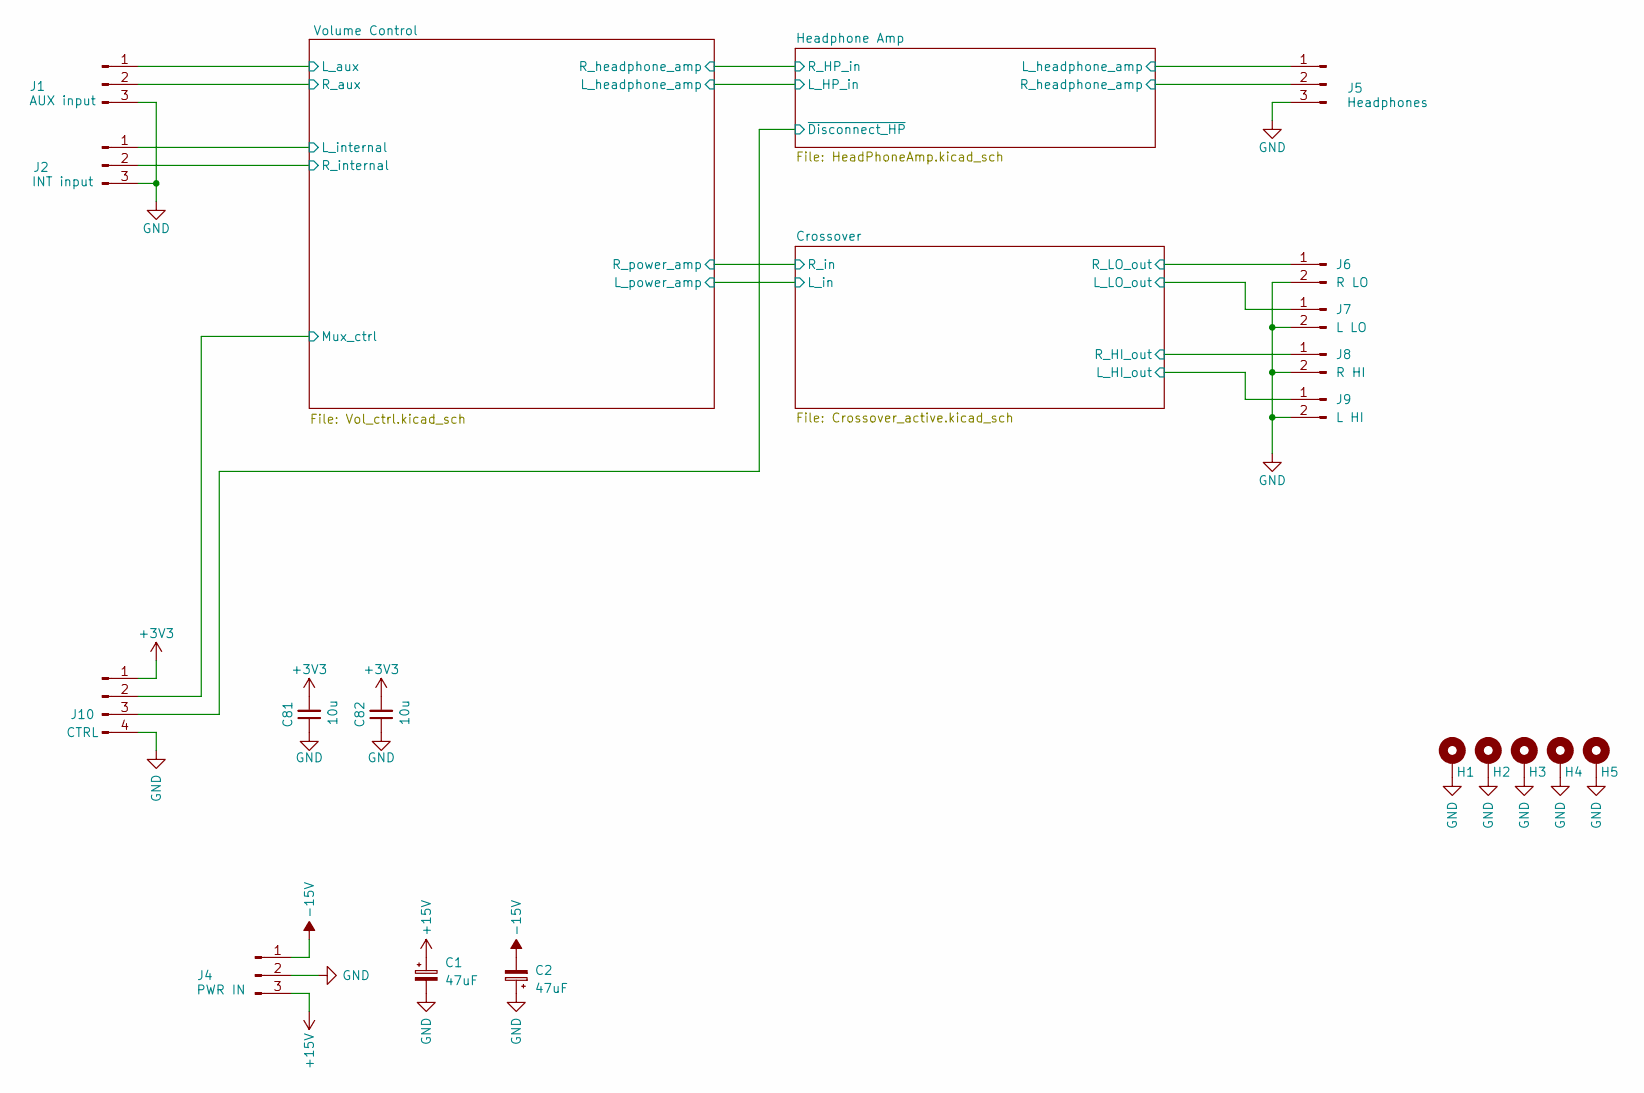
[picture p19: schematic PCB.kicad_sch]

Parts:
C1, C2: 47uF; CP_Radial_D8.0mm_P3.50mm
C81, C82: 10u; C_0805_2012Metric_Pad1.18x1.45mm_HandSolder
H1, H2, H3, H4, H5: MountingHole_Pad; MountingHole_3.2mm_M3_DIN965_Pad
J1: AUX input; PinSocket_1x03_P2.54mm_Vertical
J2: INT input; PinSocket_1x03_P2.54mm_Vertical
J4: PWR IN; JST_NV_B03P-NV_1x03_P5.00mm_Vertical
J5: Headphones; PinSocket_1x03_P2.54mm_Vertical
J6: R LO; JST_NV_B02P-NV_1x02_P5.00mm_Vertical
J7: L LO; JST_NV_B02P-NV_1x02_P5.00mm_Vertical
J8: R HI; JST_NV_B02P-NV_1x02_P5.00mm_Vertical
J9: L HI; JST_NV_B02P-NV_1x02_P5.00mm_Vertical
J10: CTRL; PinHeader_1x04_P2.54mm_Vertical

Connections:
+3V3: C81.2, C82.2, J10.1; also elsewhere on the board
+15V: C1.1, J4.3; also elsewhere on the board
-15V: C2.2, J4.1; also elsewhere on the board
/Crossover/L_HI_out: J9.1; also elsewhere on the board
/Crossover/L_LO_out: J7.1; also elsewhere on the board
/Crossover/R_HI_out: J8.1; also elsewhere on the board
/Crossover/R_LO_out: J6.1; also elsewhere on the board
/Headphone Amp/L_headphone_amp: J5.1; also elsewhere on the board
/Headphone Amp/R_headphone_amp: J5.2; also elsewhere on the board
/Headphone Amp/~Disconnect_HP: J10.3; also elsewhere on the board
/Volume Control/L_aux: J1.1; also elsewhere on the board
/Volume Control/L_internal: J2.1; also elsewhere on the board
/Volume Control/Mux_ctrl: J10.2; also elsewhere on the board
/Volume Control/R_aux: J1.2; also elsewhere on the board
/Volume Control/R_internal: J2.2; also elsewhere on the board
GND: C1.2, C2.1, C81.1, C82.1, H1.1, H2.1, H3.1, H4.1, H5.1, J1.3, J2.3, J4.2, J5.3, J6.2, J7.2, J8.2, J9.2, J10.4; also elsewhere on the board

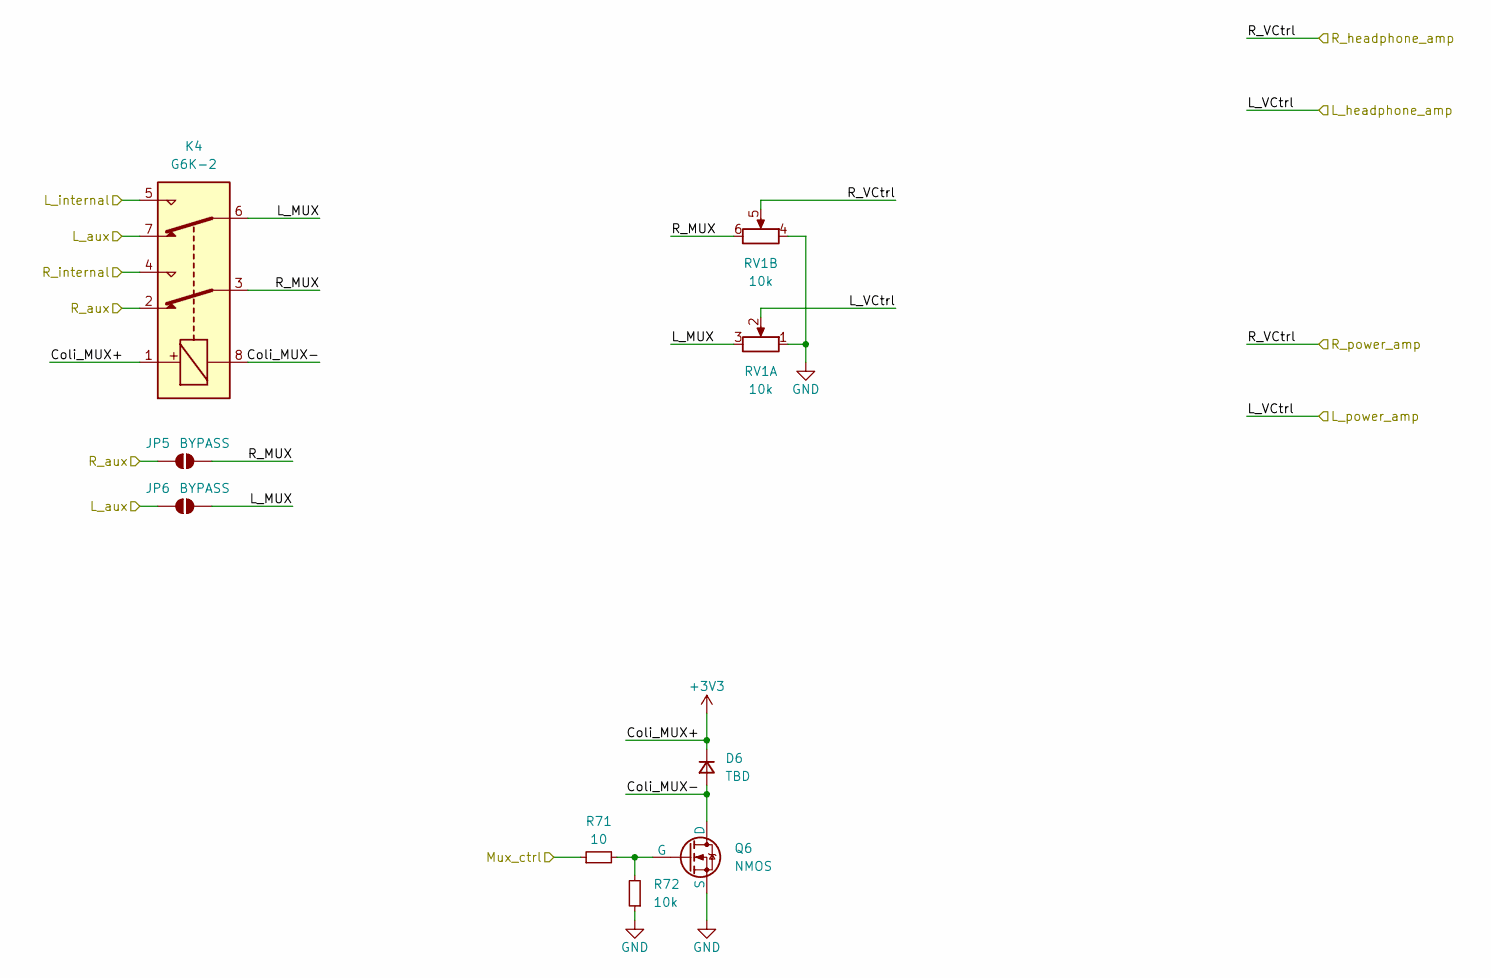
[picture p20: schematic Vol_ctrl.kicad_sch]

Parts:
D6: TBD; D_SOD-123
JP5, JP6: BYPASS; SolderJumper-2_P1.3mm_Open_RoundedPad1.0x1.5mm
K4: G6K-2; Relay_DPDT_Omron_G6K-2P
Q6: NMOS; SOT-23-Transistor
R71: 10; R_0805_2012Metric_Pad1.20x1.40mm_HandSolder
R72: 10k; R_0805_2012Metric_Pad1.20x1.40mm_HandSolder
RV1: 10k; Potentiometer_Piher_PC-16_Dual_Horizontal

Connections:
+3V3: D6.1 (K), K4.1; also elsewhere on the board
/Volume Control/Coli_MUX-: D6.2 (A), K4.8, Q6.1 (D)
/Volume Control/L_MUX: JP6.1 (A), K4.6, RV1.3
/Volume Control/L_VCtrl: RV1.2; also elsewhere on the board
/Volume Control/L_aux: JP6.2 (B), K4.7; also elsewhere on the board
/Volume Control/L_internal: K4.5; also elsewhere on the board
/Volume Control/Mux_ctrl: R71.1; also elsewhere on the board
/Volume Control/R_MUX: JP5.1 (A), K4.3, RV1.6
/Volume Control/R_VCtrl: RV1.5; also elsewhere on the board
/Volume Control/R_aux: JP5.2 (B), K4.2; also elsewhere on the board
/Volume Control/R_internal: K4.4; also elsewhere on the board
GND: Q6.3 (S), R72.1, RV1.1, RV1.4; also elsewhere on the board
unnamed: Q6.2 (G), R71.2, R72.2

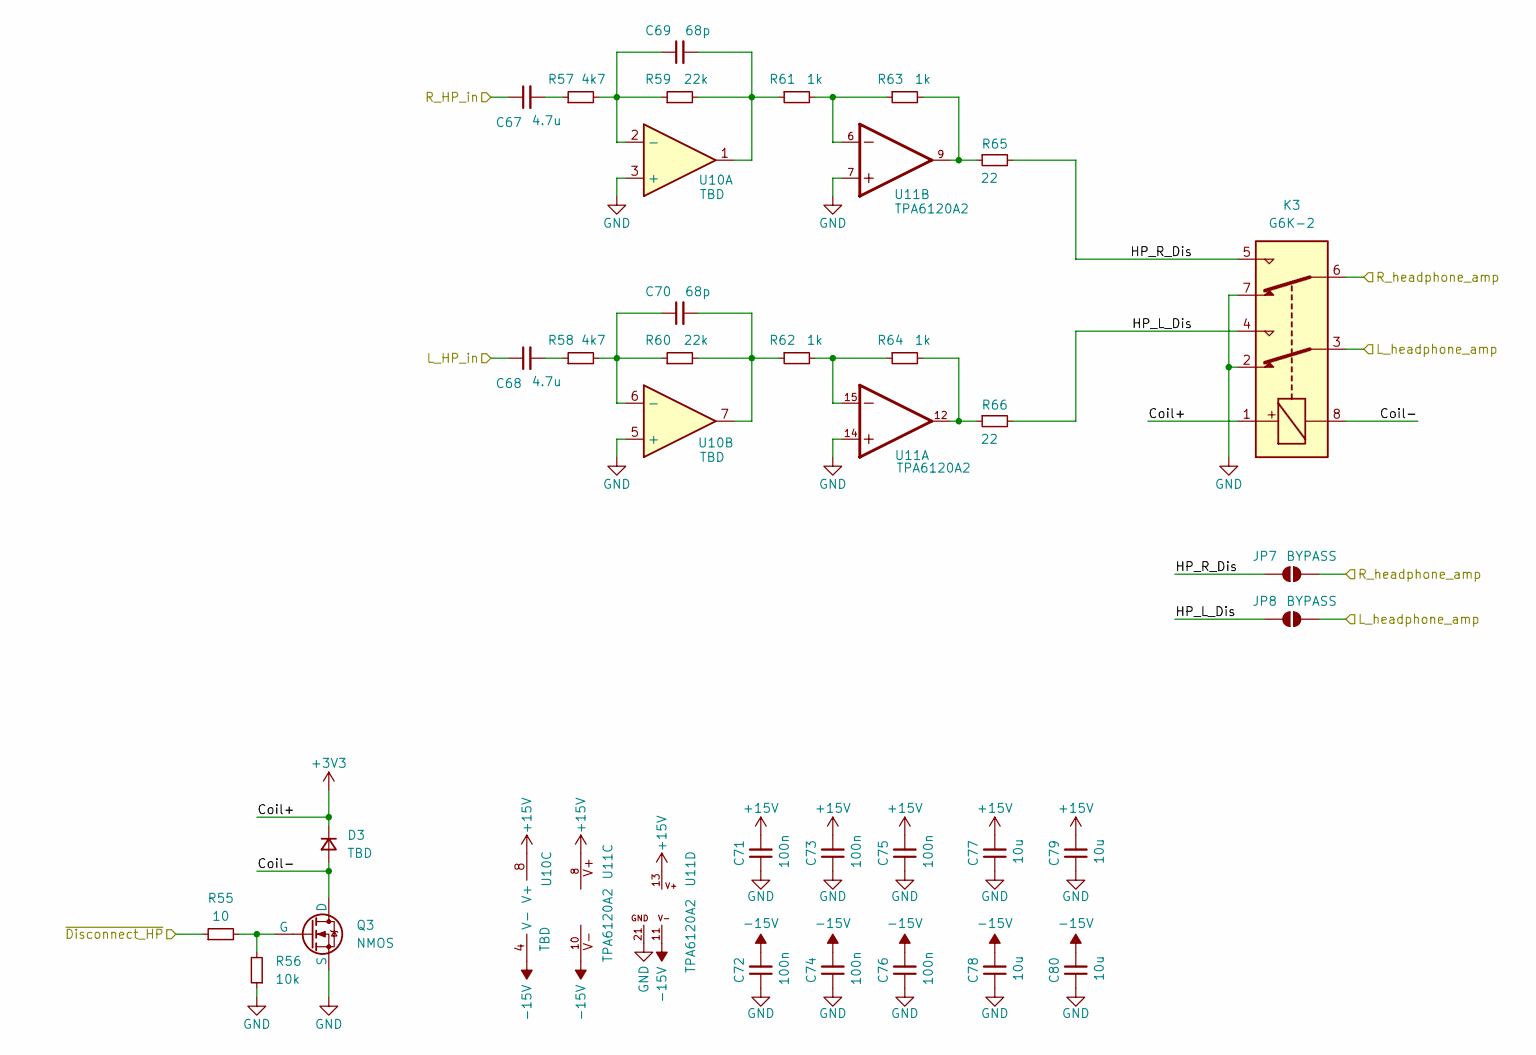
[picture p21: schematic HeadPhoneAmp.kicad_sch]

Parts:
C67, C68: 4.7u; C_Rect_L18.0mm_W7.0mm_P15.00mm_FKS3_FKP3
C69, C70: 68p; C_0805_2012Metric_Pad1.18x1.45mm_HandSolder
C71, C72, C73, C74, C75, C76: 100n; C_0805_2012Metric_Pad1.18x1.45mm_HandSolder
C77, C78, C79, C80: 10u; C_0805_2012Metric_Pad1.18x1.45mm_HandSolder
D3: TBD; D_SOD-123
JP7, JP8: BYPASS; SolderJumper-2_P1.3mm_Open_RoundedPad1.0x1.5mm
K3: G6K-2; Relay_DPDT_Omron_G6K-2P
Q3: NMOS; SOT-23-Transistor
R55: 10; R_0805_2012Metric_Pad1.20x1.40mm_HandSolder
R56: 10k; R_0805_2012Metric_Pad1.20x1.40mm_HandSolder
R57, R58: 4k7; R_0805_2012Metric_Pad1.20x1.40mm_HandSolder
R59, R60: 22k; R_0805_2012Metric_Pad1.20x1.40mm_HandSolder
R61, R62, R63, R64: 1k; R_0805_2012Metric_Pad1.20x1.40mm_HandSolder
R65, R66: 22; R_0805_2012Metric_Pad1.20x1.40mm_HandSolder
U10: TBD; SO-8_3.9x4.9mm_P1.27mm
U11: TPA6120A2; SOIC-20-EP

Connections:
+3V3: D3.1 (K), K3.1; also elsewhere on the board
+15V: C71.2, C73.2, C75.2, C77.2, C79.2, U10.8 (V+), U11.8, U11.13; also elsewhere on the board
-15V: C72.2, C74.2, C76.2, C78.2, C80.2, U10.4 (V-), U11.10, U11.11; also elsewhere on the board
/Headphone Amp/Coil-: D3.2 (A), K3.8, Q3.1 (D)
/Headphone Amp/HP_L_Dis: JP8.2 (B), K3.4, R66.2
/Headphone Amp/HP_R_Dis: JP7.2 (B), K3.5, R65.2
/Headphone Amp/L_headphone_amp: JP8.1 (A), K3.3; also elsewhere on the board
/Headphone Amp/R_headphone_amp: JP7.1 (A), K3.6; also elsewhere on the board
/Headphone Amp/~Disconnect_HP: R55.1; also elsewhere on the board
/Volume Control/L_VCtrl: C68.1; also elsewhere on the board
/Volume Control/R_VCtrl: C67.1; also elsewhere on the board
GND: C71.1, C72.1, C73.1, C74.1, C75.1, C76.1, C77.1, C78.1, C79.1, C80.1, K3.2, K3.7, Q3.3 (S), R56.1, U10.3 (+), U10.5 (+), U11.7, U11.14, U11.21, U11.P$1, U11.P$2, U11.P$3, U11.P$4; also elsewhere on the board
unnamed: C67.2, R57.1
unnamed: C68.2, R58.1
unnamed: C69.2, R59.2, R61.1, U10.1
unnamed: C70.2, R60.2, R62.1, U10.7
unnamed: Q3.2 (G), R55.2, R56.2
unnamed: R61.2, R63.1, U11.6
unnamed: R62.2, R64.1, U11.15
unnamed: R63.2, R65.1, U11.9
unnamed: R64.2, R66.1, U11.12
unnamed: C69.1, R57.2, R59.1, U10.2 (-)
unnamed: C70.1, R58.2, R60.1, U10.6 (-)

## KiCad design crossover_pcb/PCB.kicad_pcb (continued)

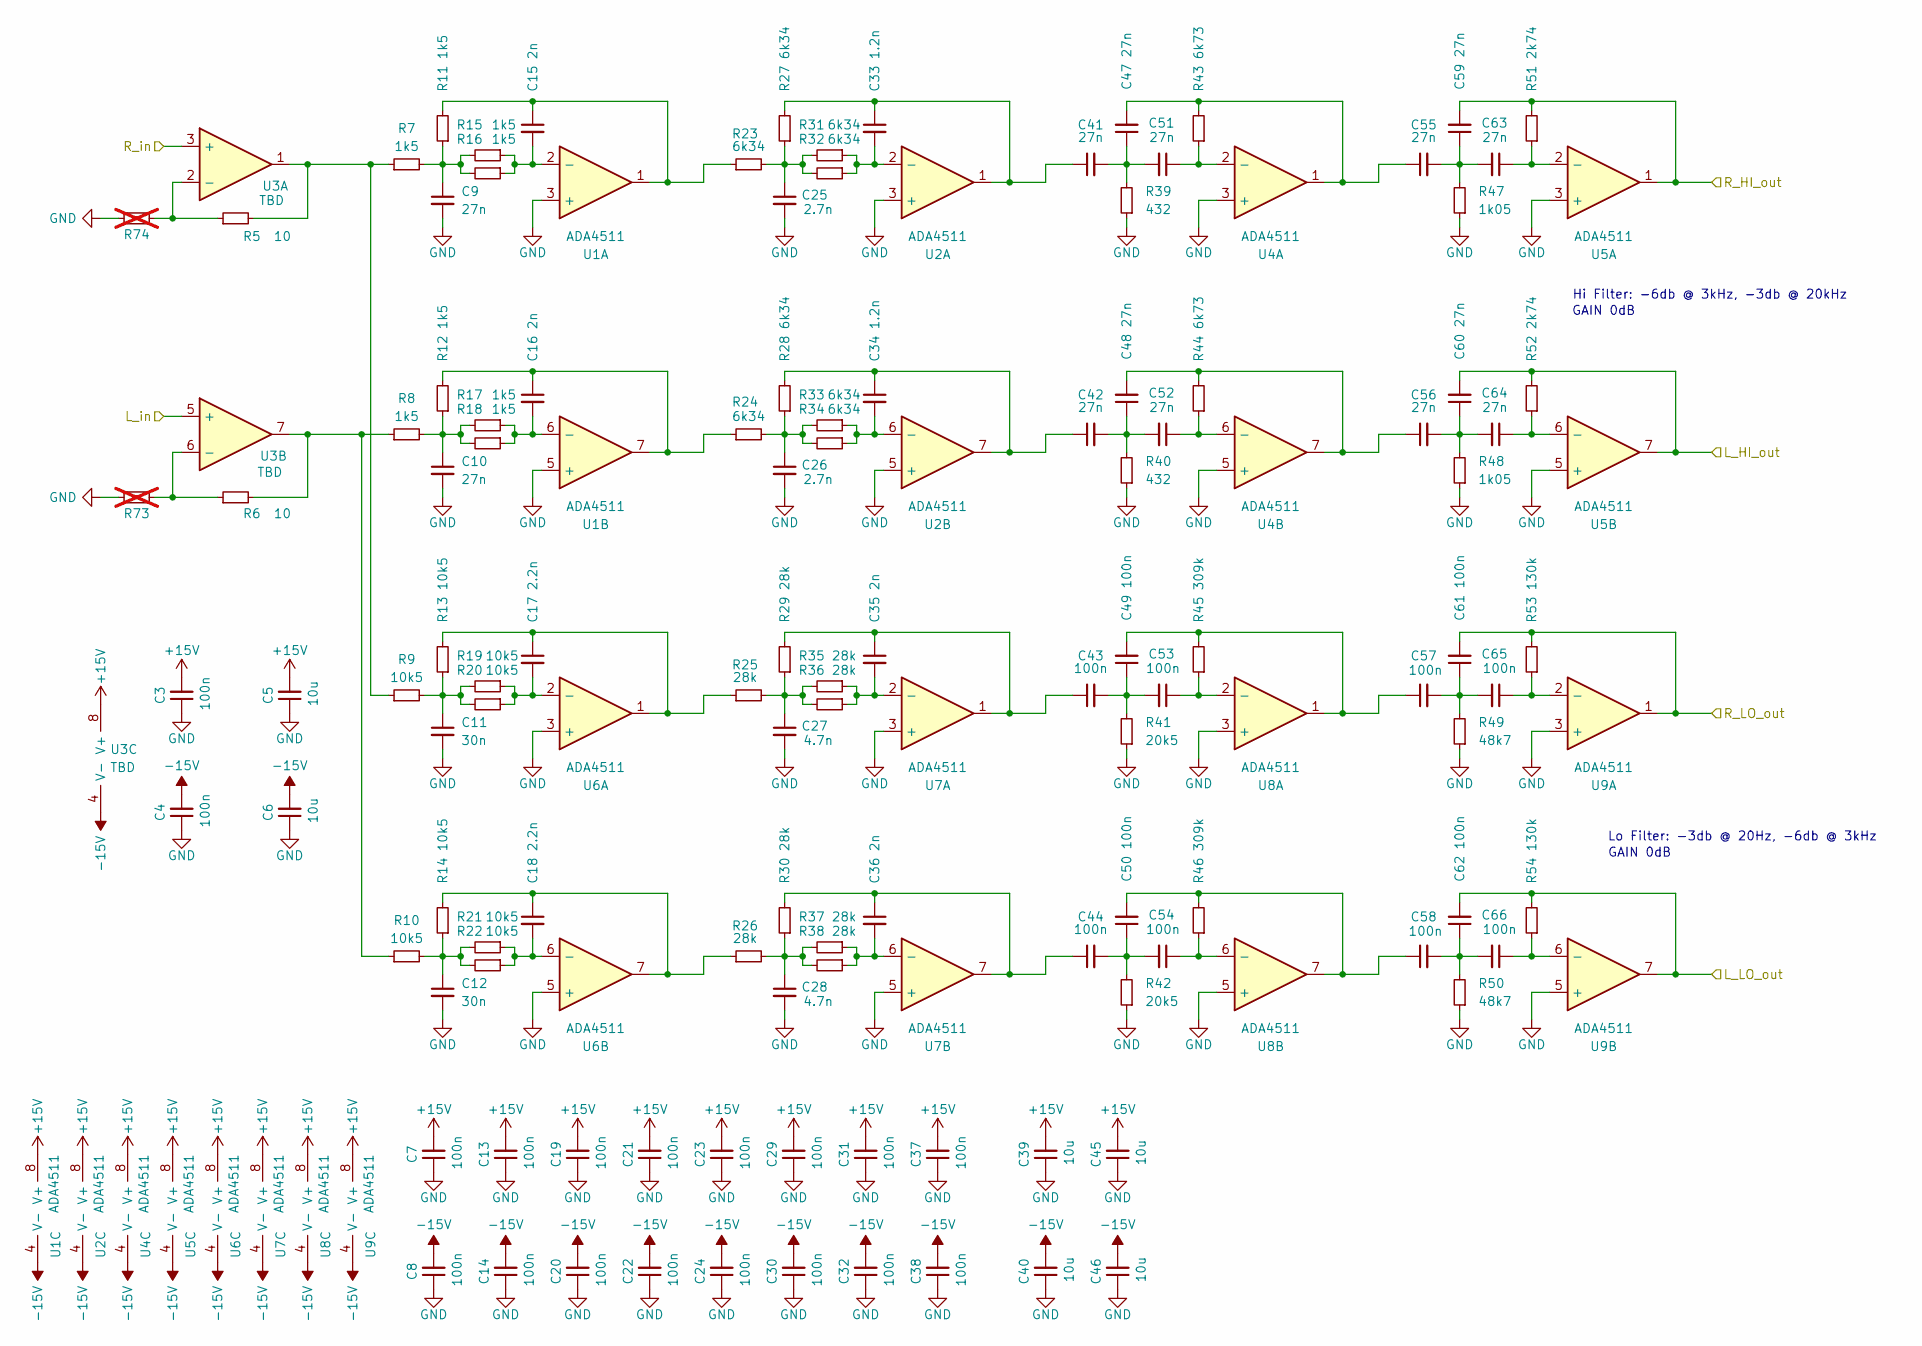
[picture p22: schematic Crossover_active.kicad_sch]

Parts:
C3, C4, C7, C8, C13, C14, C19, C20, C21, C22, C23, C24, C29, C30, C31, C32, C37, C38: 100n; C_0805_2012Metric_Pad1.18x1.45mm_HandSolder
C5, C6, C39, C40, C45, C46: 10u; C_0805_2012Metric_Pad1.18x1.45mm_HandSolder
C9, C10, C41, C42, C47, C48, C51, C52, C55, C56, C59, C60, C63, C64: 27n; C_Rect_L7.2mm_W2.5mm_P5.00mm_FKS2_FKP2_MKS2_MKP2
C11, C12: 30n; C_Rect_L7.2mm_W2.5mm_P5.00mm_FKS2_FKP2_MKS2_MKP2
C15, C16, C35, C36: 2n; C_Rect_L7.2mm_W2.5mm_P5.00mm_FKS2_FKP2_MKS2_MKP2
C17, C18: 2.2n; C_Rect_L7.2mm_W2.5mm_P5.00mm_FKS2_FKP2_MKS2_MKP2
C25, C26: 2.7n; C_Rect_L7.2mm_W2.5mm_P5.00mm_FKS2_FKP2_MKS2_MKP2
C27, C28: 4.7n; C_Rect_L7.2mm_W2.5mm_P5.00mm_FKS2_FKP2_MKS2_MKP2
C33, C34: 1.2n; C_Rect_L7.2mm_W2.5mm_P5.00mm_FKS2_FKP2_MKS2_MKP2
C43, C44, C49, C50, C53, C54, C57, C58, C61, C62, C65, C66: 100n; C_Rect_L7.2mm_W2.5mm_P5.00mm_FKS2_FKP2_MKS2_MKP2
R5, R6: 10; R_0805_2012Metric_Pad1.20x1.40mm_HandSolder
R7, R8, R11, R12, R15, R16, R17, R18: 1k5; R_0805_2012Metric_Pad1.20x1.40mm_HandSolder
R9, R10, R13, R14, R19, R20, R21, R22: 10k5; R_0805_2012Metric_Pad1.20x1.40mm_HandSolder
R23, R24, R27, R28, R31, R32, R33, R34: 6k34; R_0805_2012Metric_Pad1.20x1.40mm_HandSolder
R25, R26, R29, R30, R35, R36, R37, R38: 28k; R_0805_2012Metric_Pad1.20x1.40mm_HandSolder
R39, R40: 432; R_0805_2012Metric_Pad1.20x1.40mm_HandSolder
R41, R42: 20k5; R_0805_2012Metric_Pad1.20x1.40mm_HandSolder
R43, R44: 6k73; R_0805_2012Metric_Pad1.20x1.40mm_HandSolder
R45, R46: 309k; R_0805_2012Metric_Pad1.20x1.40mm_HandSolder
R47, R48: 1k05; R_0805_2012Metric_Pad1.20x1.40mm_HandSolder
R49, R50: 48k7; R_0805_2012Metric_Pad1.20x1.40mm_HandSolder
R51, R52: 2k74; R_0805_2012Metric_Pad1.20x1.40mm_HandSolder
R53, R54: 130k; R_0805_2012Metric_Pad1.20x1.40mm_HandSolder
R73, R74: R_0805_2012Metric_Pad1.20x1.40mm_HandSolder; not fitted
U1, U2, U4, U5, U6, U7, U8, U9: ADA4511; SO-8_3.9x4.9mm_P1.27mm
U3: TBD; SO-8_3.9x4.9mm_P1.27mm

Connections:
+15V: C3.2, C5.2, C7.2, C13.2, C19.2, C21.2, C23.2, C29.2, C31.2, C37.2, C39.2, C45.2, U1.8 (V+), U2.8 (V+), U3.8 (V+), U4.8 (V+), U5.8 (V+), U6.8 (V+), U7.8 (V+), U8.8 (V+), U9.8 (V+); also elsewhere on the board
-15V: C4.2, C6.2, C8.2, C14.2, C20.2, C22.2, C24.2, C30.2, C32.2, C38.2, C40.2, C46.2, U1.4 (V-), U2.4 (V-), U3.4 (V-), U4.4 (V-), U5.4 (V-), U6.4 (V-), U7.4 (V-), U8.4 (V-), U9.4 (V-); also elsewhere on the board
/Crossover/L_HI_out: C60.2, R52.2, U5.7; also elsewhere on the board
/Crossover/L_LO_out: C62.2, R54.2, U9.7; also elsewhere on the board
/Crossover/R_HI_out: C59.2, R51.2, U5.1; also elsewhere on the board
/Crossover/R_LO_out: C61.2, R53.2, U9.1; also elsewhere on the board
/Volume Control/L_VCtrl: U3.5 (+); also elsewhere on the board
/Volume Control/R_VCtrl: U3.3 (+); also elsewhere on the board
GND: C3.1, C4.1, C5.1, C6.1, C7.1, C8.1, C9.2, C10.2, C11.2, C12.2, C13.1, C14.1, C19.1, C20.1, C21.1, C22.1, C23.1, C24.1, C25.2, C26.2, C27.2, C28.2, C29.1, C30.1, C31.1, C32.1, C37.1, C38.1, C39.1, C40.1, C45.1, C46.1, R39.1, R40.1, R41.1, R42.1, R47.1, R48.1, R49.1, R50.1, R73.1, R74.1, U1.3 (+), U1.5 (+), U2.3 (+), U2.5 (+), U4.3 (+), U4.5 (+), U5.3 (+), U5.5 (+), U6.3 (+), U6.5 (+), U7.3 (+), U7.5 (+), U8.3 (+), U8.5 (+), U9.3 (+), U9.5 (+); also elsewhere on the board
unnamed: C9.1, R7.2, R11.1, R15.2, R16.2
unnamed: C10.1, R8.2, R12.1, R17.2, R18.2
unnamed: C11.1, R9.2, R13.1, R19.2, R20.2
unnamed: C12.1, R10.2, R14.1, R21.2, R22.2
unnamed: C15.1, R11.2, R23.1, U1.1
unnamed: C16.1, R12.2, R24.1, U1.7
unnamed: C17.1, R13.2, R25.1, U6.1
unnamed: C18.1, R14.2, R26.1, U6.7
unnamed: C25.1, R23.2, R27.1, R31.2, R32.2
unnamed: C26.1, R24.2, R28.1, R33.2, R34.2
unnamed: C27.1, R25.2, R29.1, R35.2, R36.2
unnamed: C28.1, R26.2, R30.1, R37.2, R38.2
unnamed: C33.1, C41.1, R27.2, U2.1
unnamed: C34.1, C42.1, R28.2, U2.7
unnamed: C35.1, C43.1, R29.2, U7.1
unnamed: C36.1, C44.1, R30.2, U7.7
unnamed: C41.2, C47.1, C51.2, R39.2
unnamed: C42.2, C48.1, C52.2, R40.2
unnamed: C43.2, C49.1, C53.2, R41.2
unnamed: C44.2, C50.1, C54.2, R42.2
unnamed: C47.2, C55.1, R43.2, U4.1
unnamed: C48.2, C56.1, R44.2, U4.7
unnamed: C49.2, C57.1, R45.2, U8.1
unnamed: C50.2, C58.1, R46.2, U8.7
unnamed: C55.2, C59.1, C63.2, R47.2
unnamed: C56.2, C60.1, C64.2, R48.2
unnamed: C57.2, C61.1, C65.2, R49.2
unnamed: C58.2, C62.1, C66.2, R50.2
unnamed: R5.2, R7.1, R9.1, U3.1
unnamed: R6.2, R8.1, R10.1, U3.7
unnamed: C15.2, R15.1, R16.1, U1.2 (-)
unnamed: C16.2, R17.1, R18.1, U1.6 (-)
unnamed: C33.2, R31.1, R32.1, U2.2 (-)
unnamed: C34.2, R33.1, R34.1, U2.6 (-)
unnamed: R5.1, R74.2, U3.2 (-)
unnamed: R6.1, R73.2, U3.6 (-)
unnamed: C51.1, R43.1, U4.2 (-)
unnamed: C52.1, R44.1, U4.6 (-)
unnamed: C63.1, R51.1, U5.2 (-)
unnamed: C64.1, R52.1, U5.6 (-)
unnamed: C17.2, R19.1, R20.1, U6.2 (-)
unnamed: C18.2, R21.1, R22.1, U6.6 (-)
unnamed: C35.2, R35.1, R36.1, U7.2 (-)
unnamed: C36.2, R37.1, R38.1, U7.6 (-)
unnamed: C53.1, R45.1, U8.2 (-)
unnamed: C54.1, R46.1, U8.6 (-)
unnamed: C65.1, R53.1, U9.2 (-)
unnamed: C66.1, R54.1, U9.6 (-)

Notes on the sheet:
GAIN 0dB
Hi Filter: -6db @ 3kHz, -3db @ 20kHz
Lo Filter: -3db @ 20Hz, -6db @ 3kHz

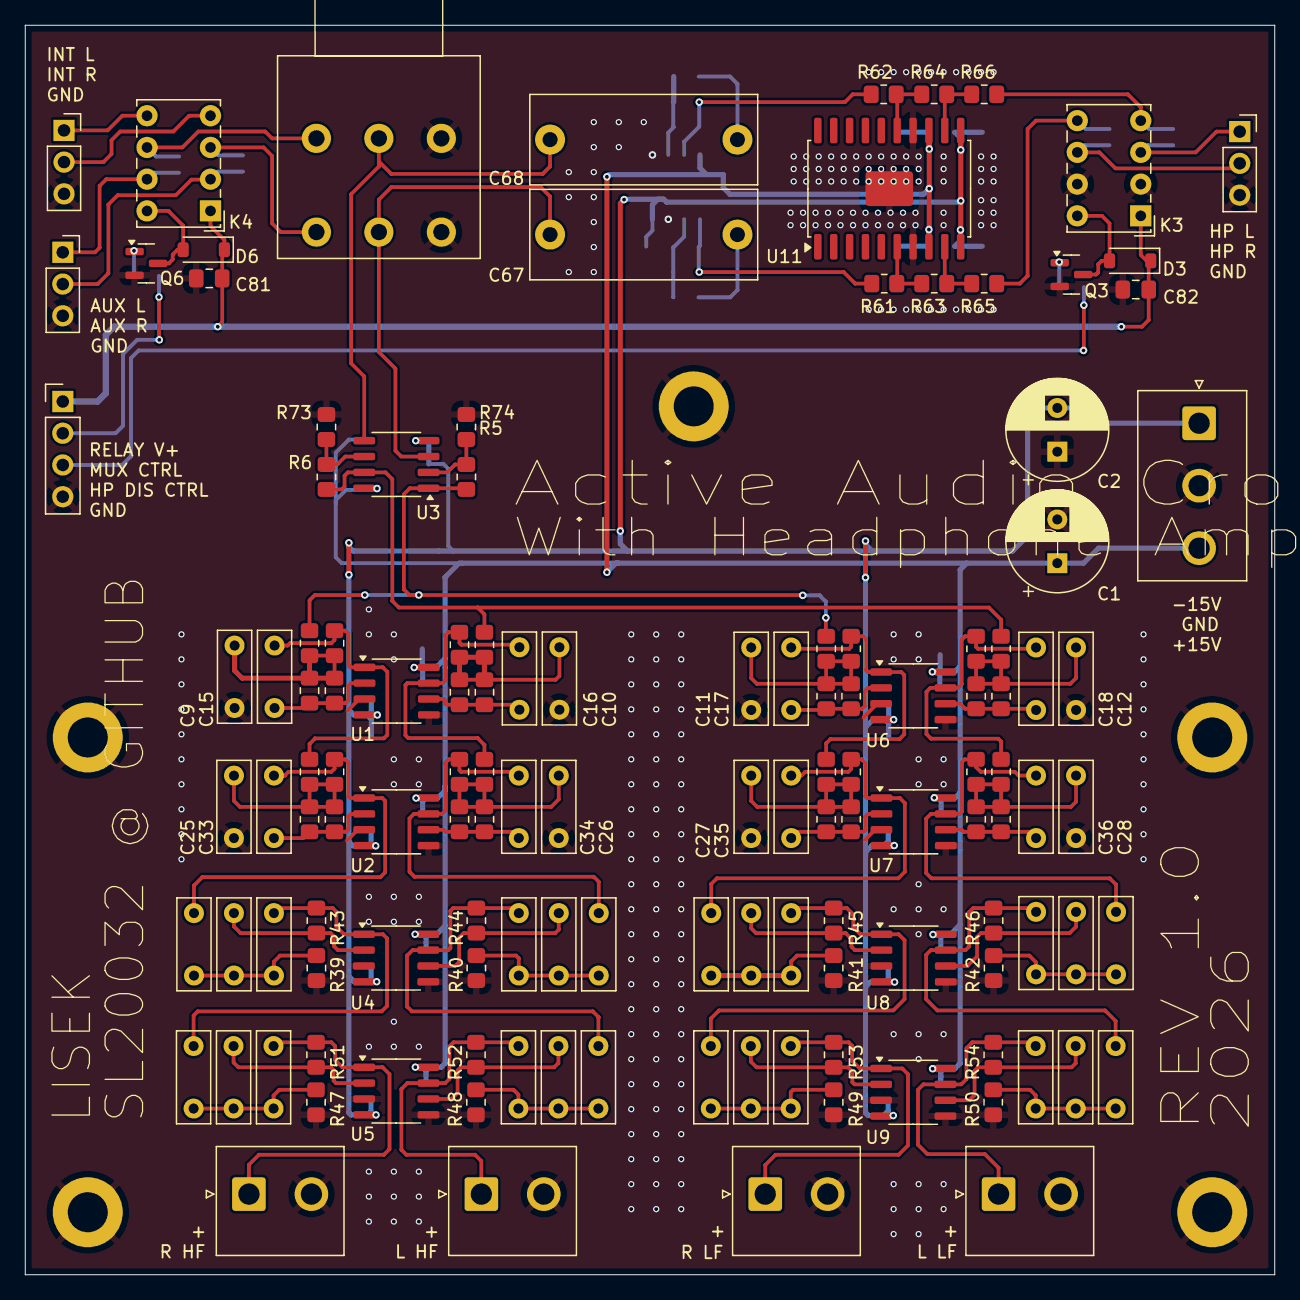
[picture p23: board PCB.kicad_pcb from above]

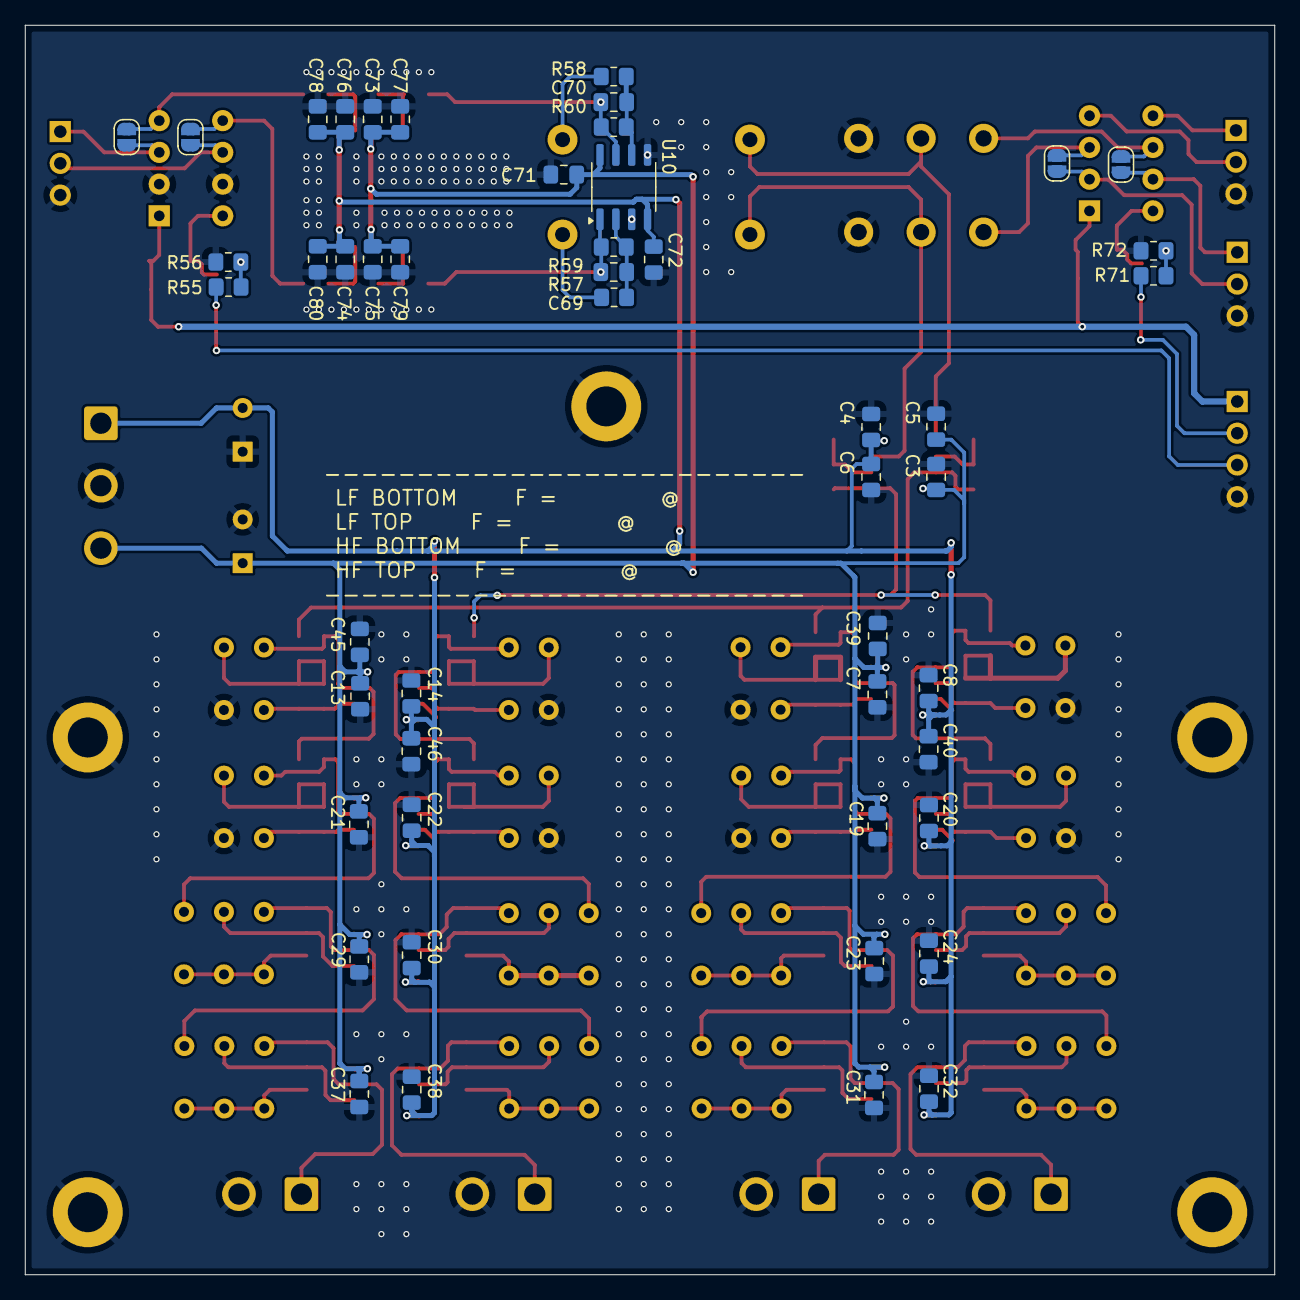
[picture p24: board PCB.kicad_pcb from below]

Board: 2 copper layers, 100.0 x 100.0 mm, 184 parts (49 on the bottom side), 84 nets.
